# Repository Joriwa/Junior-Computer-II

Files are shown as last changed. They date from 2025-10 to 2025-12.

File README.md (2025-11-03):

# Junior Computer ][ (JC2)

Junior Computer ][ Hardware and Software

## Some History

In May 1980 the dutch Elektor magazine (org. Elektuur) published the Junior Computer, developed by Alois (Loys) Nachtmann.
The Junior was a little single board computer in the style of the MOS/Commodore KIM-1.
It featured a hex keyboard and a seven segment display, 1KB RAM and 1KB ROM with the so called Print Monitor.
The computer was driven by the MOS 6502 CPU with a clock speed of 1MHz. The peripheral IC 6532, a so-called RIOT (RAM/IO/Timer), was used for input and output.
All in all, the Junior Computer was a nice little tool that gave ambitious hobby electronics enthusiasts access to programming the 
6502 CPU and enabled them to take their first steps in the world of computer-controlled electronics. 
For many people in the 1980s, the Elektor Junior Computer was the Arduino of its time.

I never had one of those wonderful little machines back in these days, but I always wanted one...

40 years later, in January 2020, I decided to make a 40th anniversary edition of the Junior.
This time it should have more memory and a better method to insert code than with the hex keyboard, but without destroying all the glory of it's original functionality.
So I gave it a whopping 32 KB of RAM, 8 KB of ROM with an extended print monitor, and a serial interface for connecting a VT100-compatible terminal.

The Junior Computer ][ was born. 

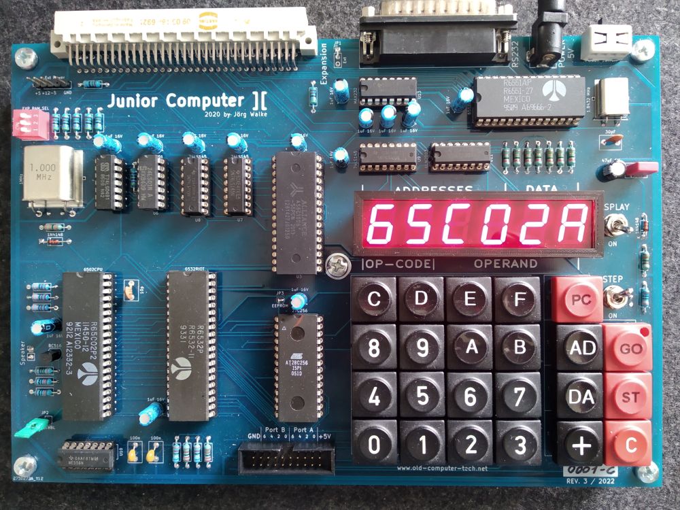
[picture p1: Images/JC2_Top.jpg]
Board Top


## The Project

For now the Junior Computer ][ has evolved various stages and some additional hardware is developed for it.

The computer it self has up to 128KB of memory. The IO-/Language card offers you a real time clock, additional parallel IO ports, 
an I2C interface, a parallel printer port, a connector for an ASCII keyboard and a Commodore Datasette drive, a 76489 sound chip, a SD-Card slot and the ability 
to program in BASIC using the EhBASIC interpreter from, the to early past away, Lee Davidson.

The Floppy-/Graphics-Controller, which is still under development, also offers you a PS/2 keyboard connection, a joystick port, a composite and RGB monitor output, and a floppy disk drive interface.

A retro style ASCII keyboard, specially developed for the Junior Computer, is also available.

There is a fork from [Emile](https://github.com/Emile666/JC2) which offers some very interesting extra features.

## Software

- M/OS 65, my little disk operating system for accessing files on SD-Card and floppy disks, is in a very early stage but already usable for loading files.

- Dietrich Lausberg ported his [CPM-65](https://github.com/Dietrich-L/CPM-65_for_JUNIOR_COMPUTER_II) to the Junior Computer][.

- Marko Lauke's port of Pacman for the [Steckschwein](https://www.steckschwein.de/) (another great new 6502 computer) is still in progress, but already looks very promising.

## Finishing

I build a wooden (bottom) case for the JC2 in a late 70's style to include all the components. The top case has to wait... 

Feel free to be inspired for building your own case.

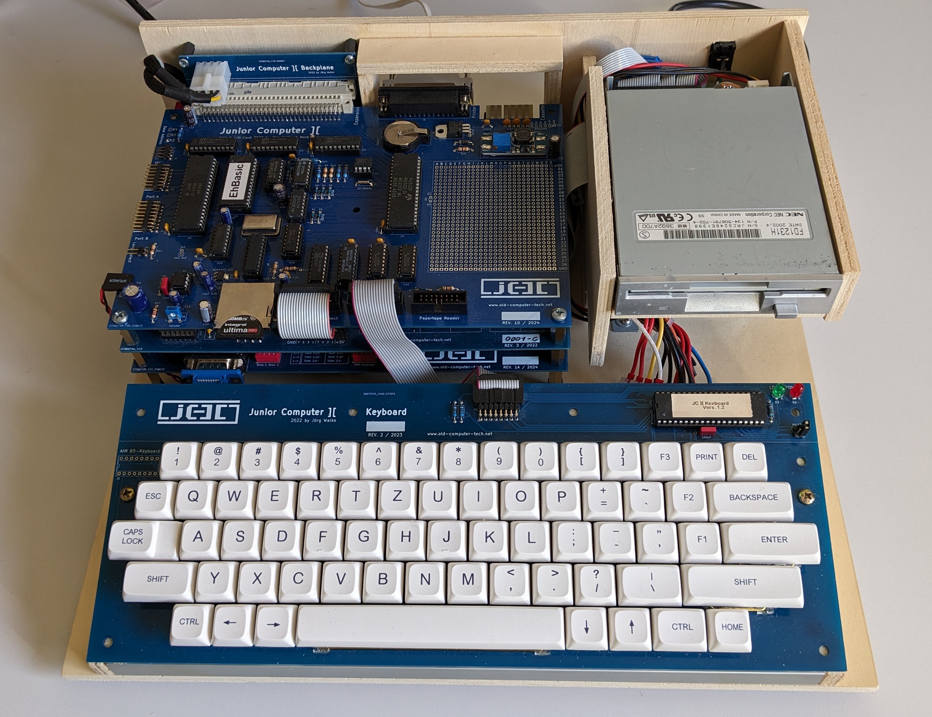
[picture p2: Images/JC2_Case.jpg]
JC2_Case


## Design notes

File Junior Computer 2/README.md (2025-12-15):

# Junior Computer 2

The Junior Computer ][ is essentially an expanded Elektor Junior Computer. It uses the same address decoding as the original, with some extra decoding to reach memory addresses beyond $1FFF.
Due to its incomplete address decoding, the Elektor Junior Computer mapped the first 8KB of the 6502's total 64KB memory space eight times in a row. 
This makes it possible to place the ROM at address range from $1C00 to $1FFF while at the same time reaching the reset and interrupt vectors at the required addresses from $FFFA to $FFFF.

The JC2 extends the address decoders of the Junior in the way to enable the use of the entire 64KB address space, without having to change any absolute addresses in the original Monitor ROM. So using old style programs should cause no problems at all.

With a 628128 RAM the JC2 can directly access 51712 bytes of free memory. The upper 64KB could be used via the 128K_SEL line on the expansion bus with some additional electronics. However, it's not currently used. 

A 6551 UART makes it possible to communitate with the JC2 via a VT100 compatible terminal or a terminal emulation such as TeraTerm, qTerm or PuTTY. The JC2 BIOS attempts to determine the baud rate used by the terminal by sending the “Send-ID” command at various baud rates until it receives a response from the connected terminal. If no response is received, JC2 uses 9600 baud, 8 bits, no parity on the COM port. You can use a little hardware patch to disable the auto baud rate detection, as described in "Hardware Patch.pdf". This patch sets the transmission rate to 19200 baud, 8 bits, no parity.

The Junior Computer ][ can be expanded with additional hardware via the 64-pin expansion bus, which is pin-compatible with the original bus interface of the Elektor Junior Computer. Therefore, old hardware expansions should also work with the JC2 but there is no guarantee that all old cards will work.

The new monitor program for the JC2 was build uppon Steve Wozniak's Apple 1 monitor program, but has since been replaced by a new implementation. However, the old postfix style of command input has been retained.

To load and save programs and data from a via RS232 connected PC to the Junior Computer's memory, I use the XModem implementation of Daryl Rictor from 2002. This uses CRC checking of the transmitted data.
In order to use CRC checking in TeraTerm, you have to modify the TeraTerm.ini file as described in the TeraTerm README.

Finally, you can make your own 3D printed cover for the 7 segment display using the JuniorLEDCover.stl file. 

## CPU

The Junior Computer ][ was originally designed for the NMOS type 6502. All code used in the BIOS is written for this CPU type. However, you can also use the Rockwell 65C02 CMOS version to reduce power consumption. The R65C02 features some additional OP-Codes. Feel free to use them for your own programs, but note that other JC2 users will not be able to run your programs without upgrading to the 65C02. 

The 6502 is still in production by Western Design Centre. They build the W65C02S CPU which is code, but not fully pin compatible to the original 6502. So you have to make some minor changes to make it fully work with the Junior Computer ][ PCB.

- The W65C02S uses pin 1 as the Vector Pull output signal, whereas the 6502 uses this as a second VSS pin, which is tied to Ground on the JC2. 
  **To solve the problem, you can remove pin 1 on your 6502 CPU IC socket or cut the trace on the component side of the PCB that connects pin 1 of the CPU socket to Ground.**

- The W65C02S also introduces a Bus Enable (BE) signal on pin 36. 
  **This signal (pin 36) must be pulled to high via a 3.3K Ohm resistor to +5V (VCC pin 8 of the CPU socket) to enable the address and data bus.**

- The RDY (Ready) signal on the W65C02S CPU is now bidirectional to monitor the WAI opcode. For this, the RDY pin is internally not pulled high any longer.
  **This signal (pin 2) must also be pulled to high via a 3.3K Ohm resistor to +5V (VCC pin 8 of the CPU socket) to enable the CPU to run.**

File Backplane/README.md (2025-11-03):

# The Backplane

The Backplane connects all your JC2 IO cards to the mainboard via the 64 pin bus connectors.
It's possible to solder a 8 pin power connector to the backplane to supply all PCBs with +5V, +12V and -5V.

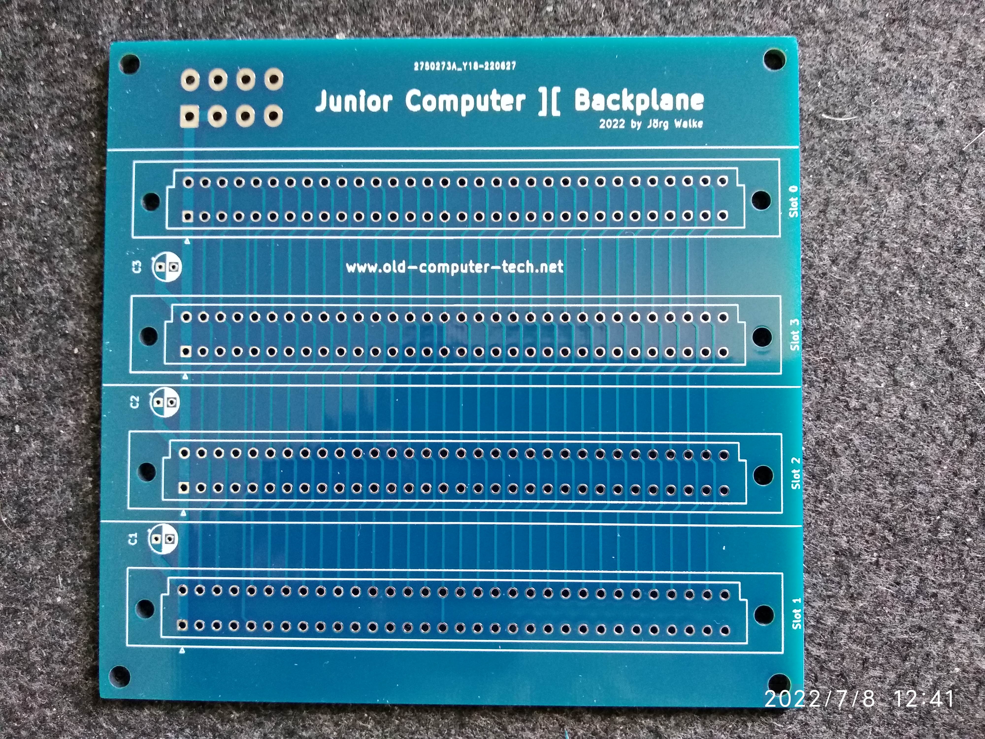
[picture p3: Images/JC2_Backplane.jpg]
JC2_Backplane


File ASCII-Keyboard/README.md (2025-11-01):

# ASCII Keyboard

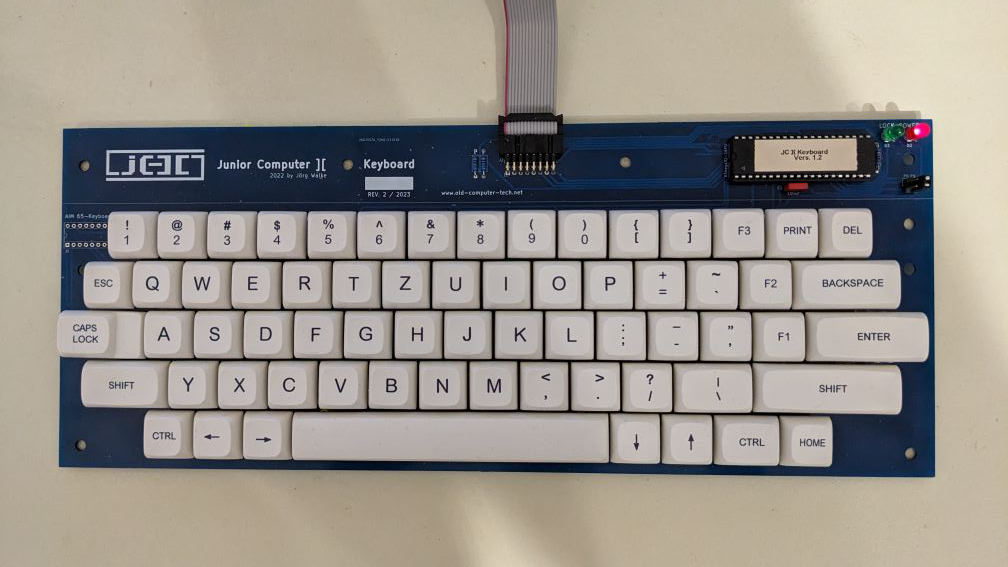
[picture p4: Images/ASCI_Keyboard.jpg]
Image top


Although the ASCII keyboard was developed specifically for the JC2, it can also be used with any other retro-style computer that can be connected to an ASCII keyboard.

Please refer to the Assembly Instruction.pdf file to find more about the pin assignment and special key combinations such as CTRL-SHIFT-DEL for a reset.

Set jumper pair P0/P1 to select desired keyboard language layout.

P0      | P1      | Keyboard Layout
--------|---------|---------------------------------------------
Open    | Open    | English US
Open    | Closed  | German
Closed  | Open    | English US (reserved for future layout)
Closed  | Closed  | English US (reserved for future layout)

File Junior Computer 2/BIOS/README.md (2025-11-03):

# Creating the BIOS

The main BIOS was assembled using the [A65](https://www.retrotechnology.com/restore/a65c.html) assembler.
In order to create a fully functional Junior Computer ][ BIOS, you must merge the assembled output of BIOS.asm with the original Monitor program. 
While BIOS.bin occupies the first 7KB of the total 8KB ROM image, MONITOR.bin uses the last 1KB. 
This last 1KB also contains the reset and interrupt vectors of the 6502 CPU. Therefore this step is absolutly necessary for a working JC2 BIOS.

However, you can use the already pre build BIOS images. "BIOS - 8K.BIN" is for a 27C64 EPROM or 28C64 EEPROM, while "BIOS - 32K.BIN" should be used for 27C256 or 28C256 ROMs.

A 32KB ROM can contain an alternative BIOS that can be selected with the ROM_BANK_SEL jumper (J4) on the JC2 mainboard. This alternative BIOS must reside from absolute ROM address $2000 to $3FFF
while the main BIOS is located between $6000 and $7FFF.

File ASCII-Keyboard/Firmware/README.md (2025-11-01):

# Firmware

To flash the ATMega32 microcontroller, you have to set the correct fuse bits as shown below.

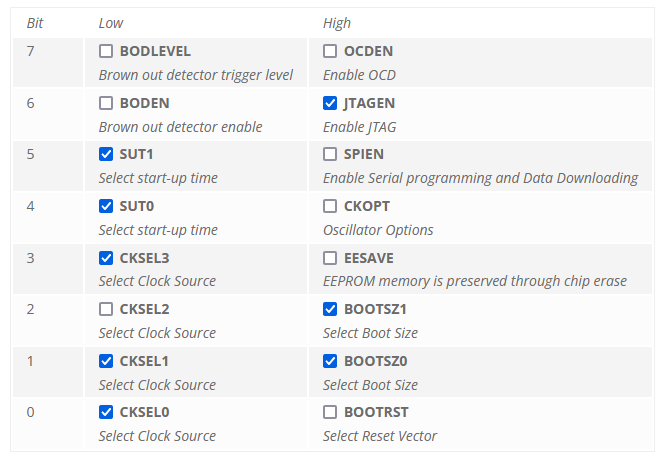
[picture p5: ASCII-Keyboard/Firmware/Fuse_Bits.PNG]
Fuse_Bits


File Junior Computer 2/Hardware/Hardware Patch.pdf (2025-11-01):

Version 1.0.2 of the BIOS includes support for a patch that can disable the automatic baud rate detection for a connected terminal and to work with the predefined speed of 19200 bauds.

For this, you must also slightly modify the Junior Computer ][ motherboard.

The simplest hardware patch is to connect pin 4 (Q3) of IC U9 (74LS145) to pin 11 (PB0) of the port connector to the left of the hex keyboard via a single wire.

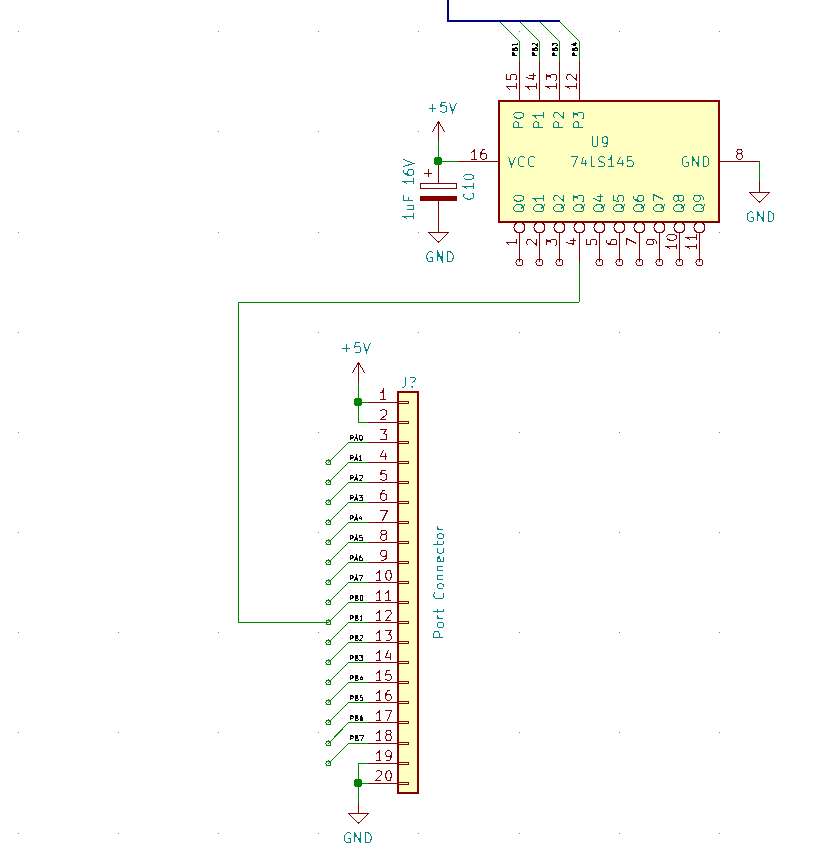
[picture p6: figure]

Figure 1. Simple patch solution

This works fine until you want to run the Junior Computer ][ without a terminal in its native Junior Computer mode using the Hex keyboard and Hex display.
Because the patch, the Junior Computer always switches into the terminal mode and the display won’t light up. To fix this issue, you can include a switch in the patch wire, to disconnect the two pins if desired.

Another solution is to exchange switch 25 (DISPLAY) into a double (toggle) switch like SW24 (STEP). If you then switch the display On (native mode), you deactivate the patch. If you insert a second switch (SW28) like in figure 2, you can additionally disable the patch completely, regardless of whether you need the Hex display or not.

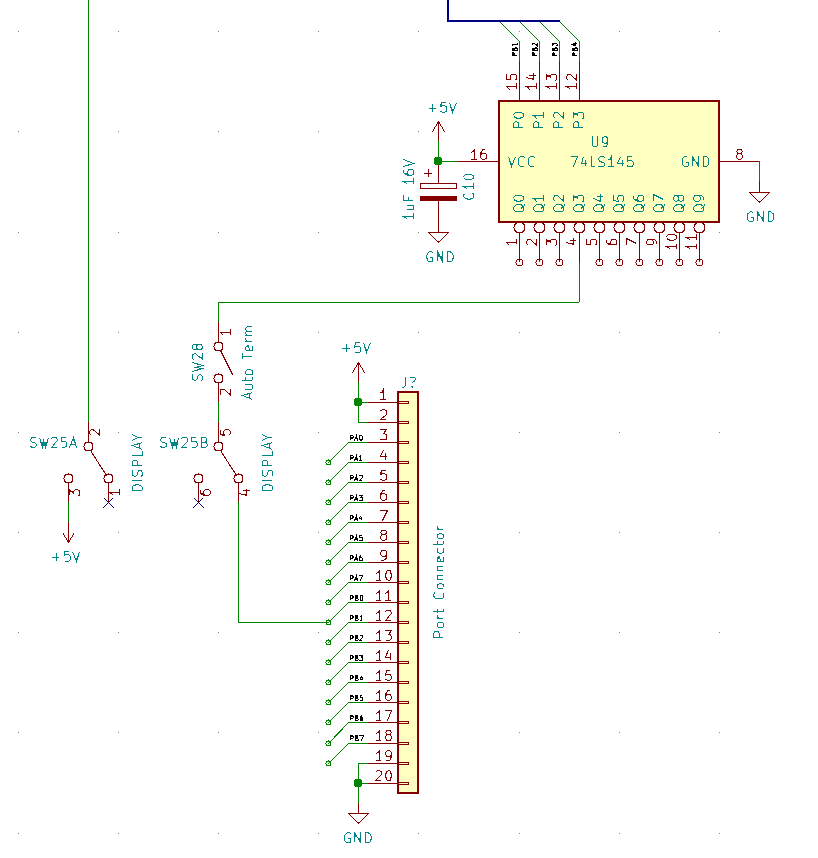
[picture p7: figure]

Figure 2. Universal patch solution

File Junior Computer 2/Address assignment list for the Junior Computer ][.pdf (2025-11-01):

## Junior Computer ][ address assignment

Address range | Size | Used by
$0000-$00FF | 256 Bytes | Zero-Page
$0100-$01FF | 256 Bytes | Stack
$0200-$07FF | 1536 Bytes | User RAM
$0800-$0BFF | 1KB | I/O area (K2)
$0C00-$0FFF | 1KB | I/O area (K3)
$1000-$13FF | 1KB | I/O area (K4)
$1400-$15FF | 512 Bytes | String- and Receive-Buffer for XMODEM communication
$1600-$17FF | 512 Bytes | 6551 ACIA serial RS232 interface
$1800-$1BFF | 1KB | 6532 RIOT, RAM, Input/Output, Timer
$1C00-$1FFF | 1KB | ROM, Junior Computer Monitor Program (mirrored address
| | range of $FC00-$FFFF)
$2000-$7FFF | 24KB | User RAM
$8000-$9FFF | 8KB | User RAM or I/O selectable via Bank80_Sel.
| | DIP-Switch $80 (ON = RAM, OFF = I/O)
$A000-$BFFF | 8KB | User RAM or I/O selectable via BankA0_Sel.
| | DIP-Switch $A0 (ON = RAM, OFF = I/O)
$C000-$DFFF | 8KB | User RAM or I/O selectable via BankC0_Sel.
| | DIP-Switch $C0 (ON = RAM, OFF = I/O)
$E000-$FFFF | 7KB | ROM, extended (serial Print) Monitor , XMODEM protocol
$FC00-$FFFF | 1KB | ROM, Junior Computer Monitor Program

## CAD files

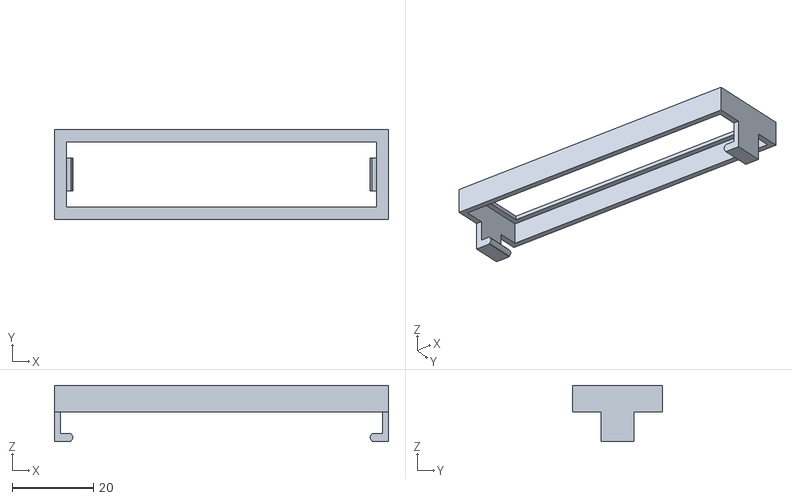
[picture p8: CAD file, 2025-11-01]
Junior Computer 2/3D Print/JuniorLEDCover.stl
82.0 x 22.0 x 13.8

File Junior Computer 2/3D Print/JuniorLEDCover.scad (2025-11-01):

$fn = 60;
/*
**  Überrahmen
*/
Xseite   =  82.0  ;   //mm
Yseite   =  22.0  ;   //mm
Zseite   =   5.5  ;   //mm
staerke  =   1.5  ;   //mm

/*
**  Filter
*/

FilterX  = 78.5 ;
FilterY  = 18.0 ;
FilterZ  = 1.0  ;

/*
**  Rahmen über LED
*/
LedX     =  78.0  ;   // led = 76 plus 2x Wand
LedY     =  18.2  ;   // led = 17,2 plus 2 x Wand
LedZ     =   5.0  ;
Wand     =   1.0  ;



module rahmen(xLength,yLength,zLength,thickness)
{
  cut = 2.0 * thickness;
  difference(){
    cube([xLength ,yLength, zLength],center = true);
    cube([xLength - cut ,yLength- cut, zLength+1],center = true);
  }
}

module Halter (){
  rahmen ( Xseite,Yseite,Zseite, staerke);
  translate ([0,0,Zseite/2.0 + 0.5]) rahmen ( Xseite,Yseite,1.0, 3.0);
}




module lippe(){
  translate ([3.5,0.0,0.0]) cylinder ( d = 2.0 , h = 8.0);
  translate ([1.0,-1.0,0.0]) cube ( [3.0,2.0,8.0]);
  translate ([0.0,-1.0,0.0]) cube ( [1.5,8.0,8.0]);
}

//lippe();

translate ([(LedX/2.0+2.0),-4.0,-9.0])  rotate([ 90.0,0.0,180.0])lippe();
translate ([-(LedX/2.0+2.0),4.0,-9.0])  rotate([ 90.0,0.0,  0.0])lippe();

Halter ();

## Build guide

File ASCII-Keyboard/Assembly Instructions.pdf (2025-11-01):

# Junior Computer ][ Keyboard rev. 2 Assembly Instructions

The assembly of the keyboard is not that easy. Therefore, please read the instructions to assemble the keyboard in the best possible way.

For assembly you need:

- A small bench vise to clamp the board vertically while you solder the key switches.
- A ruler at least 30 cm long to align the keys neatly and prevent twisting of the keys.
- Two small, strong clamps or duct tape to hold the ruler to the board.
- Of course, a soldering iron, solder, a side cutter and flat nose pliers.
- Patience and time!

Use a piece of cardboard or similar on each side of the PCB to avoid scratching the solder mask while clamping the board. Clamp the lower edge of the board horizontally in the bench vice so that it can be easily viewed from both sides.

Begin placement at the top row of the keys (1, 2, 3...).

For each row of keys, first loosely insert only the left and right keys on the PCB. Then clip the ruler with the two clamps under the two switches so that they are seated in position with as little play as possible. The keys should be aligned exactly within the silkscreen square printed on the circuit board.

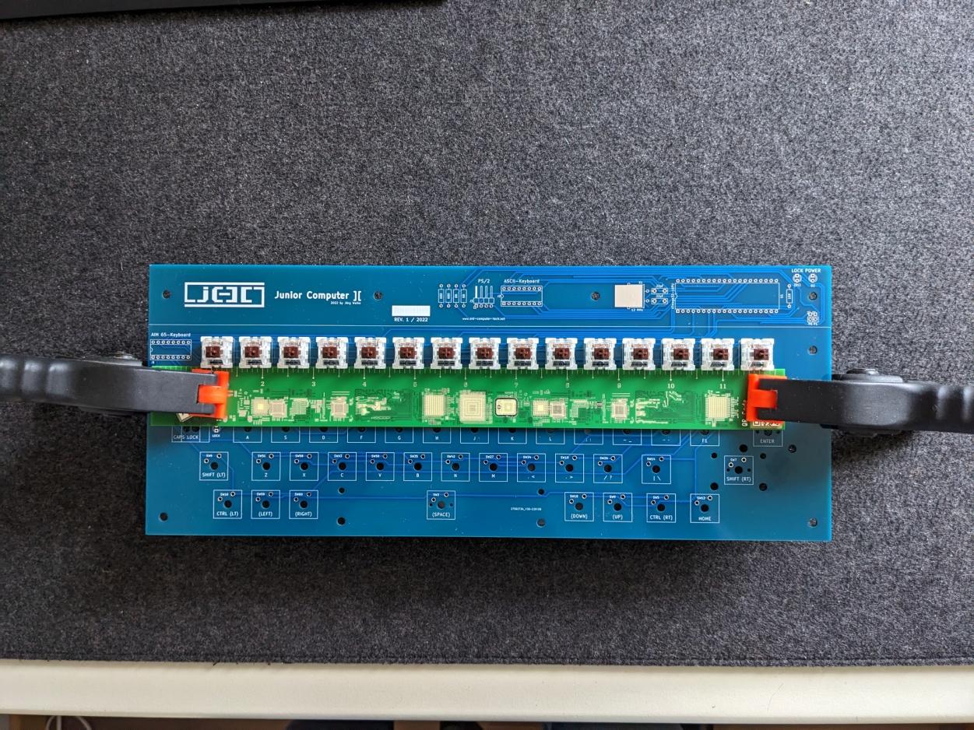
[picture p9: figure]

Press and hold the switch to be soldered with your thumb firmly on the board so that it does not shift or twist anymore and then solder one of the connection pins of the switch module. The second connection should not be soldered at this time.

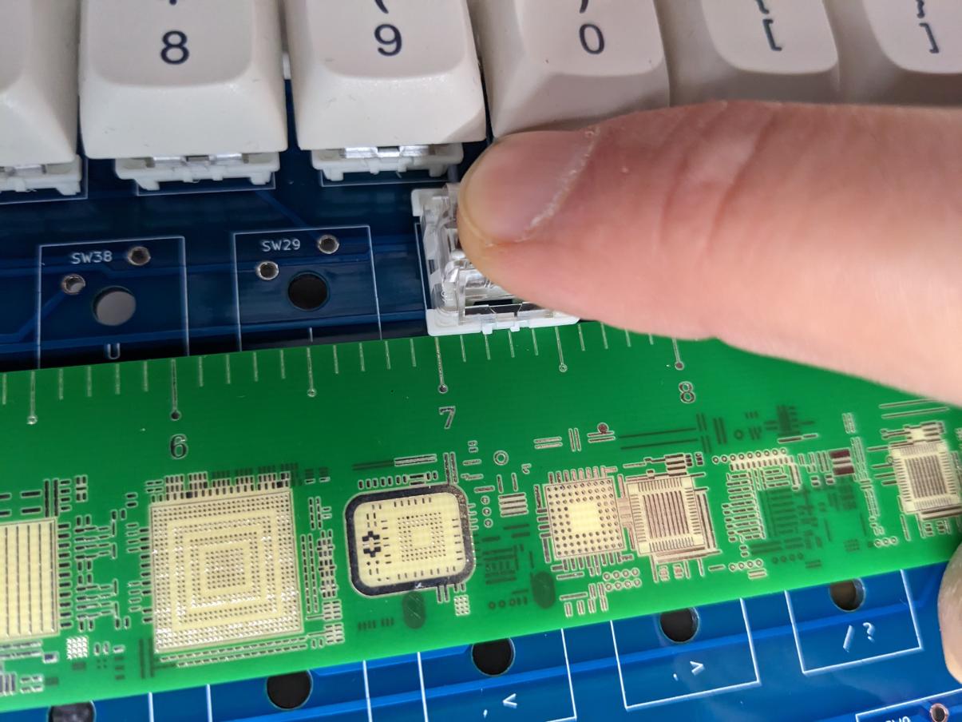
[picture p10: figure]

After that, check again, if the button is still exactly aligned to the silkscreen print and if it is not tilted in any other way. If this is not the case, re-solder the connection pin until it fits exactly.

Please take your time to get the alignment as good as possible, because every slightly twisted button will result in an unattractive appearance.

When the first two buttons of the row are properly assembled, you can now solder the second terminal pin to fix them in place.

Now equip each further switch in the row individually, as described above. The ruler helps to align the buttons at the same height. Please also leave the second connection pin unsoldered for the moment, so that you can correct any misalignment later if necessary.

When you have finished inserting a row of switches, carefully press the key caps onto the modules. This will help you to detect and correct slightly twisted or slipped buttons. Only when you are satisfied with the result, solder the remaining, second connection pins.

Equip all other rows of keys in the same way.

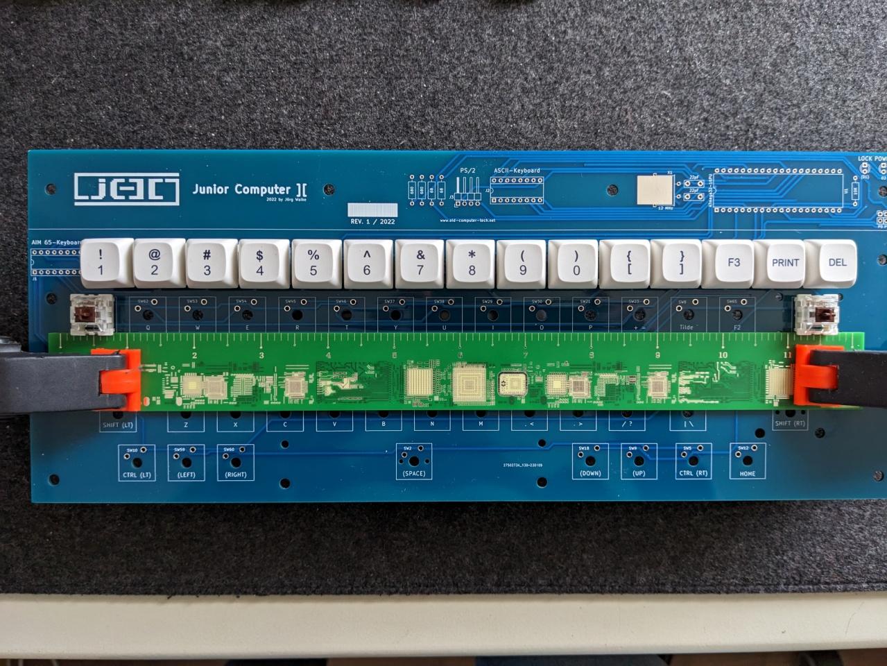
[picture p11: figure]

The key stabilizers for the wider keys are only inserted at the very end. Otherwise, they prevent the ruler from lying close to the key modules.

The keys "Backspace", "Enter", "Space" and the right "Shift" key need stabilizers. Use the key puller to remove the corresponding keycaps and possibly the keycaps of the "Home" key.

Now place the stabilizers with the two plastic noses in the two lower holes provided for the respective key. Then carefully press the two upper nubs with the metal screw connections through the holes, e.g. with a small Phillips screwdriver. Please also use some paper washers for screwing in order not to damage the solder mask with the screw heads. These are normally included with the stabilizers.

Finally assemble the three resistors, the IC socket and the LEDs according to the printed circuit board. Which LED color you take for power and which for (caps) lock is completely up to you. The Caps Lock LED D1 can be populated either on the upper right corner beside the Power LED or next to the Caps Lock key. In the second case it’s up to you to drill a hole at the right position into the Caps Lock key cap.

Pin headers P0 and P1 are used to configure the desired keyboard layout.

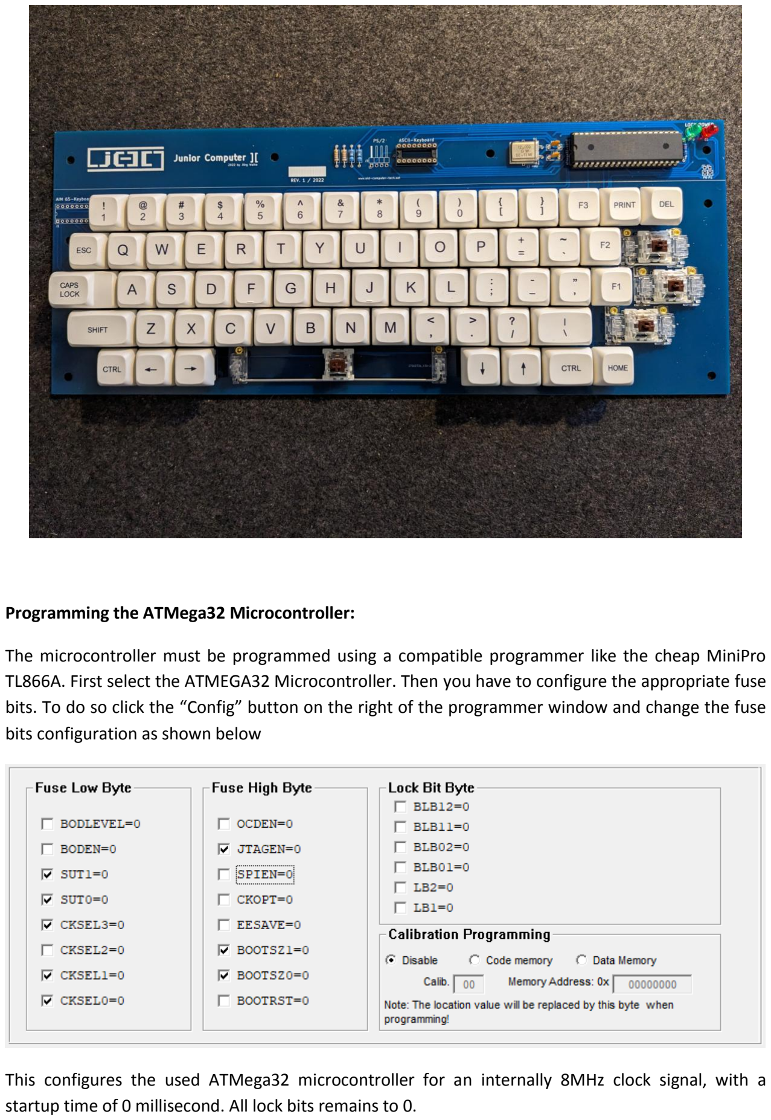
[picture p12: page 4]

Programming the ATMega32 Microcontroller:

The microcontroller must be programmed using a compatible programmer like the cheap MiniPro TL866A. First select the ATMEGA32 Microcontroller. Then you have to configure the appropriate fuse bits. To do so click the “Config” button on the right of the programmer window and change the fuse bits configuration as shown below

This configures the used ATMega32 microcontroller for an internally 8MHz clock signal, with a startup time of 0 millisecond. All lock bits remains to 0.

Then click the Code Mem0 button to switch back to the hex editor view. Load the included JC2_ASCII_Keyboard Firmware2.2.hex firmware file and click the programming button or use the menu “Device(D) -> Program(P)”. In the programming window leave all settings at the default values.

The Firmware is distributed under the Creative Commons Attribution 4.0 International License.

So you can feel free to modify the included source code file main.c to suit your needs. But if you do so, you have to give credits to me in the modified source file. To compile the source code you need the latest Microchip Studio for AVR development environment including the GNU compiler suite which can be downloaded from the Microchip website.

After you placed the microcontroller into the socket, you can apply a +5V supply voltage to the 16-pin socket (pin 2 +5V, pin 16 GND - see pin assignment). Immediately after applying the voltage the POWER LED should light up and after pressing the CAPS LOCK button once the LOCK LED should light up. A second press on CAPS LOCK switches the LED off again.

At last squeeze the two connectors onto the ribbon cable. Do this carefully to avoid accidentally breaking the connectors.

To use the keyboard on the Junior Computer ][ you need at least BIOS version 1.0.2, which can be downloaded from https://www.old-computer-tech.net/downloads and IO Board Revision 1C or newer.

Both pin 1 of the connectors on the keyboard and on the IO/Language Board is located on the left. So the cable can be plugged in 1:1.

Have fun with the keyboard

Jörg Walke, February 2024

Parts list :

Part | Count | Value | Description and Order-Link | Distributor
R1 | 1 | 10 kOhm | Metal Film Resistor 1W
R2,3 | 2 | 680 Ohm | Metal Film Resistor 1W
D1 | 1 | LED green | 5mm LED green color maybe 3mm for use in the Caps Lock
D2 | 1 | LED red | 5mm LED red color
U1 | 1 | ATMega32-16PU | ATMega32 CPU, 16 MHz
IC-Soc | 1 | IC-Socket 40 pin | 40 pin DIL precision IC-Socket
J2 | 1 | Pin Header | 2x8-pin Pin Header, angled, 2,54mm spacing
SW 1-66 | 66 | Cherry MX switch | Cherry MX switch, brown, 2 pin, 100 pcs. https://www.aliexpress.us/item/3256802260307415.html
Caps | Set | Key Caps | Milk theme key caps for MX switch mechanical keyboard. https://www.aliexpress.us/item/3256803714431360.html Set “Color” to English for US-Key Caps ! | ESC keycap Store (https://www.aliexpress.com/store/1101947944?spm=a2g0o.detail.1000007.1.153266a7Y69xRe)
Stab | Set | Key Caps Stabilizer | Mechanical Keyboard PCB Screw Stabilizers 1 x 6.25U 3 x 2U Cherry Stabilizers https://www.aliexpress.us/item/3256803460598353.html
Con1 | 1 | DIL16 crimp connector | 16 pin DIL-16 ribbon cable crimp connector for connecting to the Junior Computer ][ IO Board.
Con2 | 1 | 2x8-pin crimp connector | 2x8 pin crimp connector for ribbon cables
Cable | 1 | 16 lead ribbon cable | 30 cm, 16 lead ribbon cable

AIM 65 Connection:

The keyboard is connection compatible to an AIM 65 computer via the 16 pin DIL socket called AIM 65-Keyboard. For this the upper part of the board could also be cut off along the white separating line. If this is not done, the keyboard electronics must not be powered while an AIM 65 is connected.

If connected to an AIM 65, some additional keys will not be recognized without a change to the AIM 65 ROM, plus the keycap labels are not completely identical. The CAPS LOCK and RESET functions are generally not available on the AIM 65.

Special Keyboard Functions:

Press the SHIFT-CTRL and DEL keys simultaneously to initiate a 250 milliseconds low pulse on the /RESET line of the keyboard.

Press the HOME key to initiate a 25 milliseconds high pulse on the CLEAR_SCREEN line and generate an ASCII code (see below) on D0..D6.

Some keys on the keyboard do not have a standardized ASCII Code. The Junior Computer ][ keyboard uses the following ASCII Codes for this special keys:

Key Function | ASCII Code (decimal) and corresponding relation
LEFT ARROW | 008 Backspace (BS)
RIGHT ARROW | 021 Negative Acknowledge (NAK)
UP ARROW | 011 Vertical Tab (VT)
DOWN ARROW | 010 Line Feed (LF)
HOME | 001 Start Of Header (SOH) - CLS signal on pin 12
PRINT | 020 DC 4 (XON)
F1 | 017 DC 1
F2 | 018 DC 2 (XOFF)
F3 | 019 DC 3
CTRL-SHIFT +DEL | /RESET signal on keyboard connector pin 1
CTRL (-SHIFT) + LEFT ARROW | 006 Acknowledge (ACK). Use as Back Tab (BT)
CTRL (-SHIFT) + RIGHT ARROW | 009 Horizontal Tab (HT)
CTRL (-SHIFT) + UP ARROW | 024 Cancel. Use as Page Up (PU)
CTRL (-SHIFT) + DOWN ARROW | 012 Form Feet (FT). Use as Page Down (PD)

A key press on any key except the modifier keys (CAPS LOCK, SHIFT, and CTRL) generates a 2 microsecond low pulse on the /STROBE line. The D7 line goes low 7 microseconds before /STROBE and rises back to high 2 microseconds before /STROBE line is going low. This is used for the Junior Computer ][ as the "data available" signal.

Because data is always stable around 7 microseconds before /STROBE and stays stable until any other key is pressed, you can use the /STROBE pulse to trigger at the falling or rising edge.

The keyboard is capable of N-key roll over, which means that a freshly pressed key is detected even if another key is held down.

Pressing and holding a key for 500 milliseconds enables the auto repeat function. The standard typematic rate lies around 25 chars/s.

The keyboard generates a 7 bit ASCII code on D0..D6. The connected computer should ignore D7 for the ASCII code and set the most significant bit (MSB) of the received code to 0 (zero).

The CAPS LOCK key switches between lowercase (CAPS LOCK off) and uppercase (CAPS LOCK On) characters a..z and A..Z respectively. The number and special chars are not modified by CAPS LOCK. This is only done by pressing the SHIFT key. Pressing SHIFT while CAPS LOCK is On reverses the uppercase characters back to the lowercase ones. So CAPS LOCK behaves more like an ALPHA LOCK key.

Assignment of the 16 pin ASCII keyboard connector:

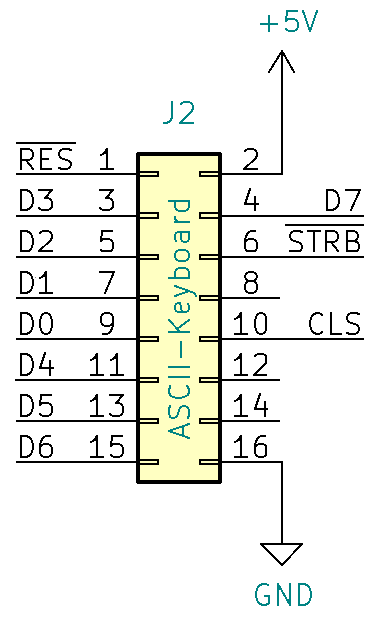
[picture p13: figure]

Top view – Pin 1 is marked as square solder pad on the PBC

Jumper P0 / P1 settings:

Set Jumper pair P0/P1 to select desired keyboard language layout.

P0 | P1 | Keyboard Layout
Open | Open | English US
Open | Closed | German
Closed | Open | English US (reserved for future layout)
Closed | Closed | English US (reserved for future layout)

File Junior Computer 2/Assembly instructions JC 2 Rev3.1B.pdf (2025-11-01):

# Junior Computer ][

2020 by Jörg Walke

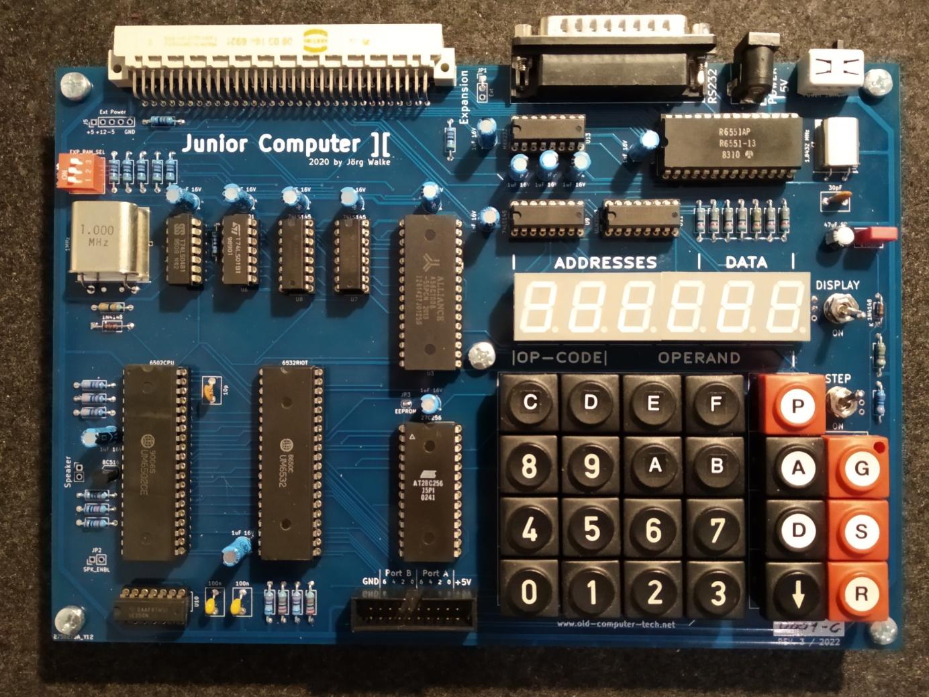
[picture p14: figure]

https://old-computer-tech.net

Preface

In May 1980 the DIY project Junior Computer was presented in the Elektor electronics magazine (originally Elektuur).

The little single-board computer was equipped with 1 KB ROM, in which the monitor program is located, 1 KB RAM (plus 128 bytes of RAM located in the 6532 RIOT), which, according to the authors, was more than enough at the time.

At the 40th anniversary of the computer, I decided to design a version with all features I wanted for the junior back in the 80s. The result is the Junior Computer ][ described here. It has 8KB ROM and a maximum of 128KB RAM. A additional serial RS232 interface and a simple sound output (as described in Junior Computer Book 2, from page 41) are also added. A 5V plug-in power supply with 2A should be sufficient. If external hardware needs to be supplied with voltage via the expansion connector, 3 Amps is recommended.

In order to be able to address the additional memory, the originally address decoding had to be extended. This is designed in such a way that the compatibility of the computer with the original Junior is preserved. An adaptation of the original monitor ROM to match the new memory location was not necessary.

Like its ancestor, the Junior Computer ][ can be expanded with external hardware via a 64-pin connection. The pin assignment oft he bus was largely retained.

In the new version, the 16 available port lines of the 6532 are available via 20-pin connector instead of a 31-pin connector.

The circuit changes mentioned here were made exclusively by me and expressly without the prior consent of the publisher Elektor, which is hopefully forgivable after 40 years. Of course, all rights to the original circuit design remain to Elektor and the authors.

Circuit diagrams, Gerber files, ROM images and other documents of the Junior Computer ][ (including this description) can be downloaded from https://old-computer-tech.net/downloads/ .

The computer and all its documents are published under the Creative Commons Attribution 4.0 license.

The original issue article, as well as the books published for the Junior Computer (volumes 1 to 4), can be downloaded from the excellent website http://retro.hansotten.nl/6502-sbc/elektuur- junior/ created by Hans Otten. Here you can also find other interesting details, programs and suggestions for the computer.

Jörg Walke , Esslingen March 20, 2022

Part | Count | Value | Description
C1 | 1 | 10pF | Ceramic capacitor
C2-C10, C14, C16-C19 | 14 | 1µF 16V | Electrolytic capacitor
C11, C12 | 2 | 100nF | Ceramic capacitor
C13 | 1 | 47µF 6V | Electrolytic capacitor
C15 | 1 | 30pF (or 27pF or 33pF) | Ceramic capacitor
D1, D2 | 2 | 1N4148 | Universal diode
Di1-Di6 | 6 | LTS-457A | 7 segment LED display 1 digit, red, common cathode, digit height 13,2 mm

or
Di1-Di6 | 2 | LTC5336WS-02 | 7 segment LED display LITEON 3 digits, red, common cathode, digit height 13,2 mm e.g. at POLLIN Electronic
R1-R3 | 3 | 3,3 K Ohm | Metal layer resistor 0,6W, 1%
R4 | 1 | 330 K Ohm | Metal layer resistor 0,6W, 1%
R5, R29 R12-R18 | 9 | 4,7 K Ohm | Metal layer resistor 0,6W, 1%
R6 | 1 | 330 Ohm | Metal layer resistor 0,6W, 1%
R7, R9 | 2 | 2,2 K Ohm | Metal layer resistor 0,6W, 1%
R8, R10 | 2 | 68 K Ohm | Metal layer resistor 0,6W, 1%
R11 | 1 | 820K | Metal layer resistor 0,6W, 1%
R19-R25 | 7 | 82 Ohm | Metal layer resistor 0,6W, 1%
R26, R27 | 2 | 10 K Ohm | Metal layer resistor 0,6W, 1%
R28 | 1 | 100 Ohm | Metal layer resistor 0,6W, 1%
U1 | 1 | R 6502 | CPU (DO NOT USE A 65C02)
U2 | 1 | 27C64, 27C128 or 27C256 or AT28C64 or AT28C256 | EPROM 8Kx8, 16Kx8 (only 8K usable) EPROM 32Kx8 (only 8K usable) EEPROM 8Kx8 (solder bridge JP3 open) EEPROM 32Kx8
U3 | 1 | W24512A or 626128 | SRAM 64Kx8 SRAM 128Kx8
U4 | 1 | UM 6532 | RIOT (RAM, Input/Output, Timer)
U5 | 1 | 74LS04 | INVERTER
U6 | 1 | 74LS01 | NAND O.C.
U7-U9 | 3 | 74LS145 | BCD Decoder O.C.
U10 | 1 | LM556 | Timer
U11 | 1 | ULN2003 | Power driver
U12 | 1 | R 6551-AP | ACIA (Asynchronious Communication Interface Adapter)
U13 | 1 | MAX232 | RS232 level shifter
X-Tal 1 | 1 | 1 MHz | Crystal, HC-33 or HC-43/U
X-Tal 2 | 1 | 1,8432 MHz | Crystal, HC-43/U
Q1 | 1 | BC516 | Darlington Transistor
LS1 | 1 | Loudspeaker 8 Ohm
J1 | 1 | DIN41612 Male 3 rows, 2x32 pin | Connector R - 64-pin, pitch 2,5 mm, THTR
J2 | 1 | D-SUB ST25-EU Male | D-SUB connector, 25-pin, angled

J3 | 1 | low voltage socket for power supply 5V DC, 2A center positiv !!! | horizontal, 6.3mm outer diameter, 2.5mm pin diameter
J4 | 1 | Pin Header 2x10 pin | Box connector 20-pol, pitch 2,5 mm
JP1 | 1 | Pin Header 1x3 | External Control Enable
JP2 | 1 | Pin Header 1x2 | Speaker Enable
JP3 | 1 | | EEPROM select
JP4 | 1 | Pin Header 1x2 with Jumper | ALT_ROM_SEL
SW26 | 1 | Slide switch POWER ON | E.g. APEM 1xOn-On or 2xOn-On pitch 2,54 mm or 5,08 mm
SW1 | 1 | Push Button Marquard 6425.0101 Keycap 826.000.071 | E.g. Conrad Labeling RST (Reset), Sticker
SW2 | 1 | Push Button Marquard 6425.0101 Keycap 826.000.071 | E.g. Conrad Labeling STP (Stop), Sticker
SW3 | 1 | Push Button Marquard 6425.0101 Keycap 826.010.011 | E.g. Conrad Labeling 0, e.g. Conrad
SW4 | 1 | Push Button Marquard 6425.0101 Keycap 826.001.011 | E.g. Conrad Labeling 1, e.g. Conrad
SW5 | 1 | Push Button Marquard 6425.0101 Keycap 826.002.011 | E.g. Conrad Labeling 2, e.g. Conrad
SW6 | 1 | Push Button Marquard 6425.0101 Keycap 826.003.011 | E.g. Conrad Labeling 3, e.g. Conrad
SW7 | 1 | Push Button Marquard 6425.0101 Keycap 826.004.011 | E.g. Conrad Labeling 4, e.g. Conrad
SW8 | 1 | Push Button Marquard 6425.0101 Keycap 826.005.011 | E.g. Conrad Labeling 5, e.g. Conrad
SW9 | 1 | Push Button Marquard 6425.0101 Keycap 826.006.011 | E.g. Conrad Labeling 6, e.g. Conrad
SW10 | 1 | Push Button Marquard 6425.0101 Keycap 826.007.011 | E.g. Conrad Labeling 7, e.g. Conrad
SW11 | 1 | Push Button Marquard 6425.0101 Keycap 826.008.011 | E.g. Conrad Labeling 8, e.g. Conrad
SW12 | 1 | Push Button Marquard 6425.0101 Keycap 826.009.011 | E.g. Conrad Labeling 9, e.g. Conrad
SW13 | 1 | Push Button Marquard 6425.0101 Keycap 826.051.011 | E.g. Conrad Labeling A, possibly Sticker
SW14 | 1 | Push Button Marquard 6425.0101 | E.g. Conrad

| | Keycap 826.052.011 | Labeling B, possibly Sticker
SW15 | 1 | Push Button Marquard 6425.0101 Keycap 826.053.011 | E.g. Conrad Labeling C, possibly Sticker
SW16 | 1 | Push Button Marquard 6425.0101 Keycap 826.054.011 | E.g. Conrad Labeling D, possibly Sticker
SW17 | 1 | Push Button Marquard 6425.0101 Keycap 826.055.011 | E.g. Conrad Labeling E, possibly Sticker
SW18 | 1 | Push Button Marquard 6425.0101 Keycap 826.056.011 | E.g. Conrad Labeling F, possibly Sticker
SW19 | 1 | Push Button Marquard 6425.0101 Keycap 826.000.011 | E.g. Conrad Labeling AD (Address), Sticker
SW20 | 1 | Push Button Marquard 6425.0101 Keycap 826.000.011 | E.g. Conrad Labeling DA (Data), Sticker
SW21 | 1 | Push Button Marquard 6425.0101 Keycap 826.017.011 | E.g. Conrad Labeling +, possibly Sticker
SW22 | 1 | Push Button Marquard 6425.0101 LED Optional Keycap 829.000.071-00 (with LED drilling) | e.g. Conrad Labeling GO, Sticker
SW23 | 1 | Push Button Marquard 6425.0101 Keycap 826.000.071 | e.g. Conrad Labeling PC, Sticker
SW24 | 1 | Toggle switch 2 x ON-ON, 5mm screw | Labeling STEP
SW25 | 1 | Toggle switch 1 x ON-ON, 5mm screw | Labeling DISPLAY
SW27 | 1 | DIP-Switch | 3xON
OPT1 | 2 | Socket strip, 1x30, 2,54 mm | Socket for LED-Display
DIL1 | 3 | DIL 14-pin | IC-Socket
DIL2 | 5 | DIL 16-pin | IC-Socket
DIL-3 | 3 (2) | DIL 28-pin | IC-Socket
DIL-4 | 1 | DIL 32-pin | IC-Socket instead of 1xDIL 28
DIL-5 | 2 | DIL 40-pin | IC-Socket

Alt
SW1-
SW23
23 | Omron B3S-1002P | Alternative input switches

### Assembly Instructions

Display

In order to raise the 7-segment LED displays to the level of the keyboard and, of course, to make it easier to replace the modules, I recommend installing two 30-pin socket. To make soldering easier, the display modules should first be plugged into the sockets before they soldered in. The solder pads 31 on the far right of the sockets are for +5V Display supply voltage. You can use it for own made plug-in PCBs such as Dot-Matrix LED Displays.

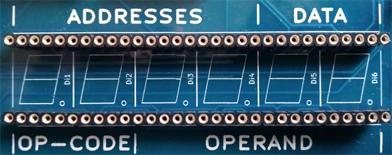
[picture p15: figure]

Instead of the six 1-digit 7-segment displays, three 2-digit or two 3-digit displays with the same digit height and a common cathode can also be installed. However, the pin assignments should be compared with the specified modules.

Keyboard

The standard Marquard button modules without a LED have a bulge in one corner and two pin bushings for an optional LED. These are suitable for the SW22's existing LED connections on the circuit board.

The cathode of the status LED for the STEP mode (button SW22, labeled GO), must be soldered to the square solder pad.

As an alternative keyboard assembly, SMD buttons with 4.5mm contact spacing can be soldered onto the existing pads.

Other Stuff

- Jumper bridge JP1 is used to enable/disable the onboard address decoder. Pin 1 is marked with a square solder pad. In the EXT position (JP1 pin 2-3), the two 74LS145 address decoders can be enabled/disabled via the pin C-30 (EXT) of the expansion slot J1. If C-30 is high , the select signals K2-K7 (K7 is equal to ROM_SEL) , RAM_SEL and the BANKx0_SEL kept high by pull-up resistors. These signals can then be activated by external hardware via the expansion slot J1 on the respective pin.
If no external control is required, JP1 must be bridged via pin 1 and 2, otherwise the computer will not start!
As an alternative, a 4.7 KOhm resistor can be soldered between pin 1 and pin 2 of JP1. Also bridge pin 2 and pin 3 of JP1. This pulls an open EXT connection at J1 to low.
- The loudspeaker amplifier can be activated with JP2. The speaker output can then be addressed as described in the Elektor Junior Computer Book 2, page 41.
- The three DIP switches (EX_RAM_SEL) can be used to page in 8KB of RAM to the specified memory area ($80 = $8000-$9FFF, $A0 = $A000-BFFF, $C0 = $C000-$EFFF).
- When using memory larger than 64KB, bank switching can be implemented via the expansion bus pin C-6 (/128K_SEL).
- The lower two kilobytes of RAM of the Junior Computer ][ are selected via the interconnected pins 1 and 2 of the BCD decoder U8 (74LS145). By connecting the (U8) IC pins 3 to 5 (or the corresponding K2 to K4 lines on the bus) with the IC pins 1 and 2 (/RAM_SEL on the bus), a maximum of three additional kilobytes of RAM can be added to the lower memory address location, if required. However, these 1-kilobyte address areas are then no longer available for any I/O expansions.
- JP3 (EEPROM) must be left open if you want to use a 64KB EEPROM, else it must be closed with a solder blob. Please note the overview table for the assignment of the Junior Computer ][ ROM socket.
- On Pin header J5 (Ext Power) the Junior Computer ][ can be connected with the supply voltages of +5V, +12V and -5V via an external power pack. Additional +12V and -5V are then available on the expansion bus for old expansion cards.
- If you want to supply your Junior Computer with a single +5V power supply via the power jack, it’s possible to generate the +12V and -5V voltages via DC-DC converters out of the +5V on J5 . The two generated voltages can then fed back to the respective pins on J5.
- The power supply connection on J3 does not have any polarity protection by a diode. Since the output voltage of a modern 5V switching power supply is almost exactly 5V, the voltage drop across a protective diode would usually be too high to safely operate the circuit.
It is therefore very important to ensure that the connector oft he power-pack is center positive, i.e. the inner pole is +5V. The following symbol should be found on the power supply unit.

If the power supply is connected incorrectly, the components of the Junior Computer ][ can be destroyed.

- The two toggle switches SW24 (STEP) and SW25 (DISPLAY) must be connected from the downside of the board as follows.

On the left the switch for DISPLAY On/Off, right STEP On/Off

- The on/off switch SW26 can be used with one or two poles either with a pitch of 2.54mm or 5.08mm.
- All component values are printed on the circuit board. A resistance value of 3k3 means 3.3KOhm, 82 means 82 Ohm.
- The plus pole of electrolytic capacitors is marked with a small + sign.
- The cathode of the diodes D1 and D2 are marked with a thicker bar in the component symbol on the circuit board.
- If the 7-segment displays are too bright or too dark, the 82 ohm series resistors R19-R25 can be varied from 68 ohms (brighter) to 120 ohms (darker).

You can use 8, 16 or 32KB (E)EPROMs on the board. However, the Junior Computer's 1-kilobyte monitor program must be located in the upper 1024 bytes of the ROM. With an 8KB EPROM it should located on address 1C00H to 1FFFH, with 16KB from 3C00H to 3FFFH and with 32KB from 7C00H to 7FFFH. The ROM images available on my side already contain the original Junior Monitor including my Extended Monitor starting from address F800H.

The revision 3.1B board contains an additional jumper (JP4) ALT_ROM_SEL, with which address line A14 can be toggled on 32KB ROMs. This means that you can use two different ROM versions.

Board revision 3b and newer, only supports 32-pin SRAMs (64KB or 128KB) with an additional CS2. This is connected to the processor clock Phi2 in order to guarantee correct memory timing with 6502 processors in CMOS design.

For older Revision 3 boards, the RAM patch must be carried out. Revision 2 boards can only be used with 1MHz 6502 NMOS processors, otherwise unexpected memory problems may occur.

### Assignment of the Junior Computer ][ ROM socket

27C256 | 27C128 | 27C64 | 28C256 | 28C64 | | Dual-In-Line-Package | | 28C64 | 28C256 | 27C64 | 27C128 | 27C256
VPP | VPP | VPP | A14 | RDY | 1 | | 28 | VCC | VCC | VCC | VCC | VCC
A12 | A12 | A12 | A12 | A12 | 2 | | 27 | WE_ | WE_ | PGM_ | PGM_ | A14
A7 | A7 | A7 | A7 | A7 | 3 | | 26 | NC | A13 | NC | A13 | A13
A6 | A6 | A6 | A6 | A6 | 4 | | 25 | A8 | A8 | A8 | A8 | A8
A5 | A5 | A5 | A5 | A5 | 5 | | 24 | A9 | A9 | A9 | A9 | A9
A4 | A4 | A4 | A4 | A4 | 6 | | 23 | A11 | A11 | A11 | A11 | A11
A3 | A3 | A3 | A3 | A3 | 7 | | 22 | OE_ | OE_ | OE_ | OE_ | OE_
A2 | A2 | A2 | A2 | A2 | 8 | | 21 | A10 | A10 | A10 | A10 | A10
A1 | A1 | A1 | A1 | A1 | 9 | | 20 | CE_ | CE_ | CE_ | CE_ | CE_/PGM
A0 | A0 | A0 | A0 | A0 | 10 | | 19 | I/O7 | I/O7 | O7 | O7 | O7
O0 | O0 | O0 | I/O0 | I/O0 | 11 | | 18 | I/O6 | I/O6 | O6 | O6 | O6
O1 | O1 | O1 | I/O1 | I/O1 | 12 | | 17 | I/O5 | I/O5 | O5 | O5 | O5
O2 | O2 | O2 | I/O2 | I/O2 | 13 | | 16 | I/O4 | I/O4 | O4 | O4 | O4
GND | GND | GND | GND | GND | 14 | | 15 | I/O3 | I/O3 | O3 | O3 | O3

### Using the solder bridge JP3 (EEPROM)

Leave solder bridge JP3 open for 28C64 assembly

Close solder bridge JP3 for 27C64/27C128/27C256/28C256 assembly

Document Version 0.1. Courtesy of Meinolf Schmid.

### Junior Computer ][ Print Monitor ROM 0.9 Usage

If no terminal is connected or detected, the behavior of the Junior Computer ][ is exactly like the original Junior Computer.

Connect a VT100 compatible terminal configured with 2400, 3600, 4800, 7200, 9600 or 19200 baud, 8 bits, no parity, 1 stop bit.

If the keyboard does not respond, select a higher baud rate (e.g. 2400 baud does not work with the ESP32 terminal).

Turn the Junior Computer ][ on.

With the latest ROM version and Rev. 3 boards with auto reset, the main screen appears immediately.

Without Auto Reset, press RST (Reset) button once.

For older ROM versions, or simply if you want to start the Print Monitor manually:

Press the AD (address) button and enter the address F800 on the hex keyboard, then confirm with the GO button.

Input is not case sensitive, so typing 'M' or 'm' is the same.

Maximum input line length is 255 characters.

In Hex Monitor:

On the promt *

- type (hex) address to show single data byte

*E000

E000- 4C

- type start-address and end-address, divided by . (dot) to show data block

*E000.E008

E000- 4C 05 E2 4C AD E3 4C 5D E0

- type address followed by : (colon) and then followed by (hex) data to enter one or more data bytes into memory

*200: 4C 00 F8

0200- 03

- type address followed by G to run user program

*200G

0200- 4C

- type Q (quit) to return to main Monitor.
- By entering M(onitor), the original Junior Computer Monitor program can be called.

More commands are described in the PrintMonitor documentation.

Since the print monitor is still under development, there are no fixed entry point addresses for helper routines. If available, I will post a list of such entry points.

### Bus Pin Assignment

a1 +5V | c1 +5V
a2 N.C. | c2 N.C.
a3 N.C. | c3 N.C.
a4 GND | c4 GND
a5 /RES | c5 RDY
a6 /128K_SEL | c6 /BANKC0_SEL
a7 D1 | c7 D0
a8 D3 | c8 D2
a9 D5 | c9 D4
a10 D7 | c10 D6
a11 /BANKA0_SEL | c11 /BANK80_SEL
a12 /IRQ | c12 /NMI
a13 N.C. | c13 N.C.
a14 K7 | c14 S0
a15 K5 | c15 K6
a16 ------------------------ c16 (a16 connected with c16)
a17 K4 | c17 +12V
a18 -5V | c18 K3
a19 A15 | c19 A14
a20 A13 | c20 A12
a21 A11 | c21 A10
a22 A9 | c22 A8
a23 A7 | c23 A6
a24 A5 | c24 A4
a25 A3 | c25 A2
a26 A1 | c26 A0
a27 PHI2 | c27 N.C.
a28 N.C. | c28 K2
a29 /RAM_SEL | c29 R/W
a30 PHI1 | c30 EXT
a31 RAM-R/W | c31 N.C.
a32 GND | c32 GND

### RS232 – SUB-D25 socket assignment

Default RS232 | Additional RS232 channel with extra assignments
Pin 2 | TxD | Pin 9 | +5V – supply voltage for ESP32 Terminal
Pin 3 | RxD | Pin 10 +5V - supply voltage for ESP32 Terminal
Pin 4 | RTS | Pin 11 +5V - supply voltage for ESP32 Terminal
Pin 5 | CTS | Pin 14 TxD - TTL Level
Pin 7 | GND | Pin 16 RxD - TTL Level
Pin 25 GND – Ground for ESP32 Terminal and CTS Pulldown

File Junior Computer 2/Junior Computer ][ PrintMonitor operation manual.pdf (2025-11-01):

## Junior Computer ][ PrintMonitor operation manual

If no terminal is connected or recognized, the Junior Computer ][ behaves exactly like the original Junior Computer.

If a VT100 compatible terminal is connected, it must be configured as follows:

2400, 3600, 4800, 7200, 9600 oder 19200 Baud
8 Bit, No Parity, 1 Stop Bit

The actual terminal baud rate is automatically recognized by the Junior Computer ][.

If the keyboard does not respond, a higher baud rate may need to be selected. For example, a transmission rate of 2400 baud will not work with the ESP32 terminal.

With the latest ROM version and a revision 3 board, an automatic power-on reset occurs and the speaker beeps once. For older versions of the board or if there is no beep, the RST (Reset) button must be pressed once.

The advanced monitor can be called manually by pressing the AD (address) key, entering the address E000 using the hex keyboard, and then pressing the GO key.

If no connected terminal is recognized, the computer jumps back to the reset address 1C1Dh of the original Junior Computer ROM. Otherwise the start screen is displayed and the hex monitor can be started by pressing the M key. If no Language Card is found, the BIOS jumps directly into the monitor and prompts you for input.

When using a terminal, you should always set the DISPLAY switch on the Junior Computer's motherboard to the OFF position to reduce power consumption. Also, the resistors just above the display will get very hot if you leave the switch in the ON position.

All inputs are not case sensitive. So 'M' and 'm' are interpreted as equal.

The maximum input length in the hex monitor is 255 characters.

The input prompt is displayed in the hex monitor

*

Here you can enter the following commands:

- Enter a hexadecimal address and confirm with <RETURN> to display the content of a single memory address.

*E000

E000- 4C

- Enter a start and end address separated by a . (period) to show a block of memory.

*E000.E008

E000- 4C DC F8 A4 F8 B1 F6 E6 F8

The listing can be interrupted at any time by pressing the <ESC> key.

- A dump command followed by a PD (print dump) command outputs the data to a connected parallel port printer.
- To change the data of a specified address, enter the address followed by : (colon).
Then enter one or more (hex) data bytes and finally confirm with <RETURN>.

*200: 4C 00 F8

- [startaddress] G (Go) jumps to a user routine and executes it

*200G

0200-R

If no start address is specified, the command jumps to the last address stored in the address register. If the called program terminates with an RTS op-code (ReTurn from Subroutine), the GO command automatically returns to the print monitor.

- Inputs can be cascaded

* E000 200.202

E000- 4C
0200- 4C 00 F8

[startaddress[.endaddress]] L (List) disassembles the 6502 instructions starting from the last specified address. If no end address is specified, the next 23 instructions are displayed.

*E000L

E000- 4C 00 F8 | JSR | $F800
E003- AD 01 16 | LDA | $1601
E006- 29 08 | AND | #$08
E008- F0 F9 | BEQ | $F808
E030- 8D 00 16 | STA | $1600

*L

E033- 60 | RTS
E034- A2 02 | LDX | #$02
- [startaddress[.endaddress]] P - like L, but outputs the data to a connected parallel port printer.

- LM (Load from Modem) starts the XMODEM/CRC read mode.

The message "Begin data transfer. Press <ESC> to abort" is shown on the terminal.

The loading process can be aborted by pressing the <ESC> key. In the terminal, select the file that you want to send to the junior computer. If the download is completed without errors, the message "Transfer successful" is displayed. Otherwise the message "Transfer error" appears and the loading process has to be repeated.

The full command is:

[startaddress [ . endaddress]] LM

where all values in square brackets are optional. If the LM command is entered without any additional parameters, the load routine reads the start address under which the data is to be stored from the first two bytes of the data stream.
If a start address is specified, the first two bytes of the data stream are ignored and the data is stored at the specified address.

The XMODEM protocol always loads and stores complete data blocks with a size of 128 bytes. If the file to be loaded has a size that is not a multiple of 128 bytes, the remaining data bytes are padded with the value 1Ah and written to memory.

By specifying an end address, overwriting of data in memory can be prevented.

Examples:

LM | reads data from an input file to the address specified in the first two bytes
2000 LM | reads data from an input file and stores it at address 2000h
300.400 LM | reads data from an input file and stores it at address 300h up to and including address 400h

After loading, the monitor returns to the prompt. There, by entering G (Go), a possibly loaded program can be executed immediately without specifying a start address.

- SM (Save to Modem) starts the XMODEM/CRC write Mode.

The message "Begin data transfer. Press <ESC> to abort” is displayed. Pressing the <ESC> key aborts the saving process. The name of the file to be received must now be selected in the terminal program. If the save process is completed without errors, the message "Transfer successful" is displayed. Otherwise the message "Transmission error" appears and the saving process has to be repeated.

The full command is:

startaddress . endaddress SM

A memory dump from the start address up to and including the end address is written to the output file.

The first two data bytes of the output file contains the start address in LSB MSB format. So with a start address of 2400h, the first two bytes are 00 24.

It is written in complete data blocks of 128 bytes each. Missing bytes are filled with the value 00h.

Example:

2000.21FF SM writes all data from address 2000h up to and including 21FFh to an output file

Your terminal or terminal emulation must support the XMODEM protocol with 16-bit CRC check. The simple checksum error detection is not supported.

- Q (Quit). Returns to the start screen.
- M (Monitor). Calls the original Junior Computer Monitor program at address 1C1Dh.

Be sure to set the DISPLAY switch on the Junior Computer‘s Mainboard to the ON position if you jump from terminal mode to the original monitor.

### Extended Commands

If you have connected the IO/Language Card to your Junior Computer ][, you can use the following monitor commands to save and load data from a connected Commodore 1530/1531 or compatible Datasette drive. The IO board uses the standard board edge connector that is used on PET, VIC20 or C64 computers. However, the storage format of the Junior ][ is not compatible to that of these computers. It is much faster and more compact, but also reliable.

- LT (Load from Tape). This command loads previously saved data from tape.

„Press PLAY, <ESC> to cancel.“ is displayed on the terminal. If you press the <ESC> key, the command is canceled. After you press the PLAY key on your attached Datasette drive, the next file on tape is read back into the memory. The start address on where the data is stored is read from the tape file header.

The full command is:

LT [“filename“]

where filename is optional. If the LT command is entered without a filename, the next file that is found on tape will be read into memory. This is the same as giving an empty (““) or a star (“*“) string as a filename.

However, if a filename is given, all files with different file names are skipped until the matching on is found. You can append a star character to your given filename. This allows you to search for the next file whose filename starts with the given string, but does not have to match with the then following characters.

You can always break the loading by pressing the STOP key on the Datasette drive.

If a file could not correctly read back from tape, a LOAD ERROR is shown.

- ST (Save to Tape). Store data onto a tape drive. The data file is written to tape with a simple XOR checksum to detect bit errors.

The full command is:

startaddress . endaddress ST “filename“

A filename must be given for the storage file. However it can be an empty string (““) or a star (“*“). In this case the data is saved as an unnamed file.

On the Terminal the message „Press PLAY & RECORD, <ESC> to cancel.“ is displayed. You can press the <ESC> key to cancel the command. After pressing the PLAY and RECORD button at the same time, the data from memory will be written to tape from the specified start address to the given end address.

You can always break the data storage by pressing the STOP key on the Datasette drive.

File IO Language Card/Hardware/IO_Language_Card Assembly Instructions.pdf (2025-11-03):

# Parts List for the Junior Computer ][ IO/Language Card Rev. 1D

Reference | Quantity | Value | Description and Order-Link | Distributor
C1-C8, C14,C24,C26 | 11 | 100nF | KERKO 100N (https://www.reichelt.de/keramik-kondensator-100-nf-20-80-y5v-50-100-v-rm-5-kerko-100n-p9265.html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) Ceramic (https://www.reichelt.de/keramik-kondensator-100-nf-20-80-y5v-50-100-v-rm-5-kerko-100n-p9265.html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) C (https://www.reichelt.de/keramik-kondensator-100-nf-20-80-y5v-50-100-v-rm-5-kerko-100n-p9265.html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)apacitor (https://www.reichelt.de/keramik-kondensator-100-nf-20-80-y5v-50-100-v-rm-5-kerko-100n-p9265.html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), 5m (https://www.reichelt.de/keramik-kondensator-100-nf-20-80-y5v-50-100-v-rm-5-kerko-100n-p9265.html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)m (https://www.reichelt.de/keramik-kondensator-100-nf-20-80-y5v-50-100-v-rm-5-kerko-100n-p9265.html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) spacing (https://www.reichelt.de/keramik-kondensator-100-nf-20-80-y5v-50-100-v-rm-5-kerko-100n-p9265.html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) | Reichelt.de
C9,C12,C13 | 3 | 10uF 16V | RAD 10/35 (https://www.reichelt.de/elko-radial-10-f-35-v-rm-2-0-85-c-2000h-20--rad-10-35-p23716.html?trstct=pol_0&nbc=1) Electrolytic (https://www.reichelt.de/elko-radial-10-f-35-v-rm-2-0-85-c-2000h-20--rad-10-35-p23716.html?trstct=pol_0&nbc=1) C (https://www.reichelt.de/elko-radial-10-f-35-v-rm-2-0-85-c-2000h-20--rad-10-35-p23716.html?trstct=pol_0&nbc=1)apacitor (https://www.reichelt.de/elko-radial-10-f-35-v-rm-2-0-85-c-2000h-20--rad-10-35-p23716.html?trstct=pol_0&nbc=1), radial, (https://www.reichelt.de/elko-radial-10-f-35-v-rm-2-0-85-c-2000h-20--rad-10-35-p23716.html?trstct=pol_0&nbc=1) 2. (https://www.reichelt.de/elko-radial-10-f-35-v-rm-2-0-85-c-2000h-20--rad-10-35-p23716.html?trstct=pol_0&nbc=1)5m (https://www.reichelt.de/elko-radial-10-f-35-v-rm-2-0-85-c-2000h-20--rad-10-35-p23716.html?trstct=pol_0&nbc=1)m (https://www.reichelt.de/elko-radial-10-f-35-v-rm-2-0-85-c-2000h-20--rad-10-35-p23716.html?trstct=pol_0&nbc=1) spacing (https://www.reichelt.de/elko-radial-10-f-35-v-rm-2-0-85-c-2000h-20--rad-10-35-p23716.html?trstct=pol_0&nbc=1) | Reichelt.de
C10 | 1 | 220uF 35V | RAD 220/35 (https://www.reichelt.de/elko-radial-220-f-35-v-rm-5-0-85-c-2000h-20--rad-220-35-p15120.html?search=RAD+220/35) Electrolytic (https://www.reichelt.de/elko-radial-220-f-35-v-rm-5-0-85-c-2000h-20--rad-220-35-p15120.html?search=RAD+220/35) C (https://www.reichelt.de/elko-radial-220-f-35-v-rm-5-0-85-c-2000h-20--rad-220-35-p15120.html?search=RAD+220/35)apacitor (https://www.reichelt.de/elko-radial-220-f-35-v-rm-5-0-85-c-2000h-20--rad-220-35-p15120.html?search=RAD+220/35), radial, (https://www.reichelt.de/elko-radial-220-f-35-v-rm-5-0-85-c-2000h-20--rad-220-35-p15120.html?search=RAD+220/35) 5m (https://www.reichelt.de/elko-radial-220-f-35-v-rm-5-0-85-c-2000h-20--rad-220-35-p15120.html?search=RAD+220/35)m (https://www.reichelt.de/elko-radial-220-f-35-v-rm-5-0-85-c-2000h-20--rad-220-35-p15120.html?search=RAD+220/35) spacing (https://www.reichelt.de/elko-radial-220-f-35-v-rm-5-0-85-c-2000h-20--rad-220-35-p15120.html?search=RAD+220/35) | Reichelt.de
C11 | 1 | 47nF 63V | MMK 47n 63 (https://www.reichelt.de/folienkondensator-47nf-63v-100-c-mmk-47n-63-p206603.html?search=MMK+47n) Film (https://www.reichelt.de/folienkondensator-47nf-63v-100-c-mmk-47n-63-p206603.html?search=MMK+47n) C (https://www.reichelt.de/folienkondensator-47nf-63v-100-c-mmk-47n-63-p206603.html?search=MMK+47n)apacitor (https://www.reichelt.de/folienkondensator-47nf-63v-100-c-mmk-47n-63-p206603.html?search=MMK+47n), (https://www.reichelt.de/folienkondensator-47nf-63v-100-c-mmk-47n-63-p206603.html?search=MMK+47n) 5m (https://www.reichelt.de/folienkondensator-47nf-63v-100-c-mmk-47n-63-p206603.html?search=MMK+47n)m spacing (https://www.reichelt.de/folienkondensator-47nf-63v-100-c-mmk-47n-63-p206603.html?search=MMK+47n) | Reichelt.de
C15-C17 | 3 | 470pF | KERKO 470P (https://www.reichelt.de/keramik-kondensator-470p-kerko-470p-p9295.html?&trstct=pos_0&nbc=1) Ceramic (https://www.reichelt.de/keramik-kondensator-470p-kerko-470p-p9295.html?&trstct=pos_0&nbc=1) C (https://www.reichelt.de/keramik-kondensator-470p-kerko-470p-p9295.html?&trstct=pos_0&nbc=1)apacitor 2. (https://www.reichelt.de/keramik-kondensator-470p-kerko-470p-p9295.html?&trstct=pos_0&nbc=1)5mm (https://www.reichelt.de/keramik-kondensator-470p-kerko-470p-p9295.html?&trstct=pos_0&nbc=1) spacing (https://www.reichelt.de/keramik-kondensator-470p-kerko-470p-p9295.html?&trstct=pos_0&nbc=1) | Reichelt.de
C18-C21 | 4 | 1uF 16V | RAD 1/63 (https://www.reichelt.de/elko-radial-1-0-f-63-v-rm-2-0-85-c-2000h-20--rad-1-63-p15096.html?trstct=pol_1&nbc=1) Electrolytic (https://www.reichelt.de/elko-radial-1-0-f-63-v-rm-2-0-85-c-2000h-20--rad-1-63-p15096.html?trstct=pol_1&nbc=1) C (https://www.reichelt.de/elko-radial-1-0-f-63-v-rm-2-0-85-c-2000h-20--rad-1-63-p15096.html?trstct=pol_1&nbc=1)apacitor (https://www.reichelt.de/elko-radial-1-0-f-63-v-rm-2-0-85-c-2000h-20--rad-1-63-p15096.html?trstct=pol_1&nbc=1), radial, (https://www.reichelt.de/elko-radial-1-0-f-63-v-rm-2-0-85-c-2000h-20--rad-1-63-p15096.html?trstct=pol_1&nbc=1) 2. (https://www.reichelt.de/elko-radial-1-0-f-63-v-rm-2-0-85-c-2000h-20--rad-1-63-p15096.html?trstct=pol_1&nbc=1)5m (https://www.reichelt.de/elko-radial-1-0-f-63-v-rm-2-0-85-c-2000h-20--rad-1-63-p15096.html?trstct=pol_1&nbc=1)m (https://www.reichelt.de/elko-radial-1-0-f-63-v-rm-2-0-85-c-2000h-20--rad-1-63-p15096.html?trstct=pol_1&nbc=1) spacing (https://www.reichelt.de/elko-radial-1-0-f-63-v-rm-2-0-85-c-2000h-20--rad-1-63-p15096.html?trstct=pol_1&nbc=1) | Reichelt.de
C22 | 1 | 100nF | MMK 100n 100 (https://www.reichelt.de/folienkondensator-100nf-100v-100-c-mmk-100n-100-p206605.html?search=MMK100n) Film (https://www.reichelt.de/folienkondensator-100nf-100v-100-c-mmk-100n-100-p206605.html?search=MMK100n) C (https://www.reichelt.de/folienkondensator-100nf-100v-100-c-mmk-100n-100-p206605.html?search=MMK100n)apacitor (https://www.reichelt.de/folienkondensator-100nf-100v-100-c-mmk-100n-100-p206605.html?search=MMK100n), 5m (https://www.reichelt.de/folienkondensator-100nf-100v-100-c-mmk-100n-100-p206605.html?search=MMK100n)m (https://www.reichelt.de/folienkondensator-100nf-100v-100-c-mmk-100n-100-p206605.html?search=MMK100n) spacing (https://www.reichelt.de/folienkondensator-100nf-100v-100-c-mmk-100n-100-p206605.html?search=MMK100n) | Reichelt.de
C23,C25 | 2 | 10uF 6,3V | RAD 10/35 (https://www.reichelt.de/elko-radial-10-f-35-v-rm-2-0-85-c-2000h-20--rad-10-35-p23716.html?trstct=pol_0&nbc=1) Electrolytic (https://www.reichelt.de/elko-radial-10-f-35-v-rm-2-0-85-c-2000h-20--rad-10-35-p23716.html?trstct=pol_0&nbc=1) C (https://www.reichelt.de/elko-radial-10-f-35-v-rm-2-0-85-c-2000h-20--rad-10-35-p23716.html?trstct=pol_0&nbc=1)apacitor (https://www.reichelt.de/elko-radial-10-f-35-v-rm-2-0-85-c-2000h-20--rad-10-35-p23716.html?trstct=pol_0&nbc=1), radial, (https://www.reichelt.de/elko-radial-10-f-35-v-rm-2-0-85-c-2000h-20--rad-10-35-p23716.html?trstct=pol_0&nbc=1) 2. (https://www.reichelt.de/elko-radial-10-f-35-v-rm-2-0-85-c-2000h-20--rad-10-35-p23716.html?trstct=pol_0&nbc=1)5m (https://www.reichelt.de/elko-radial-10-f-35-v-rm-2-0-85-c-2000h-20--rad-10-35-p23716.html?trstct=pol_0&nbc=1)m (https://www.reichelt.de/elko-radial-10-f-35-v-rm-2-0-85-c-2000h-20--rad-10-35-p23716.html?trstct=pol_0&nbc=1) spacing (https://www.reichelt.de/elko-radial-10-f-35-v-rm-2-0-85-c-2000h-20--rad-10-35-p23716.html?trstct=pol_0&nbc=1) | Reichelt.de
D1-D7,D9-D10 | 9 | BAT46 | BAT 46 (https://www.reichelt.de/kleinsignal-schottky-diode-100-v-150-ma-do-35-bat-46-p4853.html?search=bat46) Schottk (https://www.reichelt.de/kleinsignal-schottky-diode-100-v-150-ma-do-35-bat-46-p4853.html?search=bat46)y (https://www.reichelt.de/kleinsignal-schottky-diode-100-v-150-ma-do-35-bat-46-p4853.html?search=bat46) Diode (https://www.reichelt.de/kleinsignal-schottky-diode-100-v-150-ma-do-35-bat-46-p4853.html?search=bat46) | Reichelt.de
D8 | 1 | 1N4004 | 1N4004 (https://www.reichelt.de/gleichrichterdiode-400-v-1-a-do-41-1n-4004-p1726.html?&trstct=pos_0&nbc=1) D (https://www.reichelt.de/gleichrichterdiode-400-v-1-a-do-41-1n-4004-p1726.html?&trstct=pos_0&nbc=1)iode (https://www.reichelt.de/gleichrichterdiode-400-v-1-a-do-41-1n-4004-p1726.html?&trstct=pos_0&nbc=1) | Reichelt.de
R1-R4 | 4 | 4.7 KOhm | 1W 4. (https://www.reichelt.de/widerstand-metalloxyd-4-7-kohm-0207-1-0-w-5--1w-4-7k-p1822.html?search=1W+4,7K)7K (https://www.reichelt.de/widerstand-metalloxyd-4-7-kohm-0207-1-0-w-5--1w-4-7k-p1822.html?search=1W+4,7K) M (https://www.reichelt.de/widerstand-metalloxyd-4-7-kohm-0207-1-0-w-5--1w-4-7k-p1822.html?search=1W+4,7K)e (https://www.reichelt.de/widerstand-metalloxyd-4-7-kohm-0207-1-0-w-5--1w-4-7k-p1822.html?search=1W+4,7K)tal (https://www.reichelt.de/widerstand-metalloxyd-4-7-kohm-0207-1-0-w-5--1w-4-7k-p1822.html?search=1W+4,7K) Film (https://www.reichelt.de/widerstand-metalloxyd-4-7-kohm-0207-1-0-w-5--1w-4-7k-p1822.html?search=1W+4,7K) Resistor (https://www.reichelt.de/widerstand-metalloxyd-4-7-kohm-0207-1-0-w-5--1w-4-7k-p1822.html?search=1W+4,7K) | Reichelt.de
R5-R7,R10, R14-R16, R18,R19 | 9 | 10 KOhm | 1W 10K (https://www.reichelt.de/widerstand-metalloxyd-10-kohm-0207-1-0-w-5--1w-10k-p1779.html?search=1W+10K) Metal (https://www.reichelt.de/widerstand-metalloxyd-10-kohm-0207-1-0-w-5--1w-10k-p1779.html?search=1W+10K) Film (https://www.reichelt.de/widerstand-metalloxyd-10-kohm-0207-1-0-w-5--1w-10k-p1779.html?search=1W+10K) Resistor (https://www.reichelt.de/widerstand-metalloxyd-10-kohm-0207-1-0-w-5--1w-10k-p1779.html?search=1W+10K) | Reichelt.de
R8 | 1 | 1.2 KOhm | 1W 1. (https://www.reichelt.de/widerstand-metalloxyd-1-2-kohm-0207-1-0-w-5--1w-1-2k-p1768.html?search=1W+1,2K)2K (https://www.reichelt.de/widerstand-metalloxyd-1-2-kohm-0207-1-0-w-5--1w-1-2k-p1768.html?search=1W+1,2K) Metal (https://www.reichelt.de/widerstand-metalloxyd-1-2-kohm-0207-1-0-w-5--1w-1-2k-p1768.html?search=1W+1,2K) Film (https://www.reichelt.de/widerstand-metalloxyd-1-2-kohm-0207-1-0-w-5--1w-1-2k-p1768.html?search=1W+1,2K) Resistor (https://www.reichelt.de/widerstand-metalloxyd-1-2-kohm-0207-1-0-w-5--1w-1-2k-p1768.html?search=1W+1,2K) | Reichelt.de
R9 | 1 | 10 Ohm | 1W 10 (https://www.reichelt.de/widerstand-metalloxyd-10-ohm-0207-1-0-w-5--1w-10-p1776.html?search=1W+10) Metal (https://www.reichelt.de/widerstand-metalloxyd-10-ohm-0207-1-0-w-5--1w-10-p1776.html?search=1W+10) Film (https://www.reichelt.de/widerstand-metalloxyd-10-ohm-0207-1-0-w-5--1w-10-p1776.html?search=1W+10) Resistor (https://www.reichelt.de/widerstand-metalloxyd-10-ohm-0207-1-0-w-5--1w-10-p1776.html?search=1W+10) | Reichelt.de
R12,R13 | 2 | 3.3 KOhm | 1W 3. (https://www.reichelt.de/widerstand-metalloxid-3-3-kohm-0207-1-0-w-5--1w-3-3k-p1808.html?search=1W+3,3K)3K (https://www.reichelt.de/widerstand-metalloxid-3-3-kohm-0207-1-0-w-5--1w-3-3k-p1808.html?search=1W+3,3K) Metal (https://www.reichelt.de/widerstand-metalloxid-3-3-kohm-0207-1-0-w-5--1w-3-3k-p1808.html?search=1W+3,3K) Film (https://www.reichelt.de/widerstand-metalloxid-3-3-kohm-0207-1-0-w-5--1w-3-3k-p1808.html?search=1W+3,3K) Resistor (https://www.reichelt.de/widerstand-metalloxid-3-3-kohm-0207-1-0-w-5--1w-3-3k-p1808.html?search=1W+3,3K) | Reichelt.de
R17 | 1 | 2.2 KOhm | 1W 2. (https://www.reichelt.de/widerstand-metalloxyd-2-2-kohm-0207-1-0-w-5--1w-2-2k-p1794.html?search=1W+2,2K)2K (https://www.reichelt.de/widerstand-metalloxyd-2-2-kohm-0207-1-0-w-5--1w-2-2k-p1794.html?search=1W+2,2K) Metal (https://www.reichelt.de/widerstand-metalloxyd-2-2-kohm-0207-1-0-w-5--1w-2-2k-p1794.html?search=1W+2,2K) Film (https://www.reichelt.de/widerstand-metalloxyd-2-2-kohm-0207-1-0-w-5--1w-2-2k-p1794.html?search=1W+2,2K) Resistor (https://www.reichelt.de/widerstand-metalloxyd-2-2-kohm-0207-1-0-w-5--1w-2-2k-p1794.html?search=1W+2,2K) | Reichelt.de
RV1 | 1 | 10 KOhm | ACP 14-S 10K trim. Potentiometer (https://www.reichelt.de/de/de/shop/produkt/einstellpotentiometer_stehend_10_kohm_14_mm-110298) | Reichelt.de
Q1 | 1 | TIP125 | TIP125 (https://www.reichelt.de/de/de/shop/produkt/darlington-transistor_pnp_60v_5a_2w_to-220ab-217344) Darlington Transistor, PNP (https://www.reichelt.de/de/de/shop/produkt/darlington-transistor_pnp_60v_5a_2w_to-220ab-217344) | Reichelt.de
U1,U2,U13 | 3 | 74LS244 | SN 74LS244N TEX (https://www.reichelt.de/buffer-3-state-4-75--5-25-v-dil-20-sn-74ls244n-tex-p216948.html?search=74LS244) Buffer (https://www.reichelt.de/buffer-3-state-4-75--5-25-v-dil-20-sn-74ls244n-tex-p216948.html?search=74LS244), 3-State, DIL-20 (https://www.reichelt.de/buffer-3-state-4-75--5-25-v-dil-20-sn-74ls244n-tex-p216948.html?search=74LS244) | Reichelt.de
U3 | 1 | 74LS245 | LS 245 Transceiver, (https://www.reichelt.de/transceiver-octal-4-75--5-25-v-dip-20-ls-245-p10667.html?&trstct=pos_0&nbc=1) Octal (https://www.reichelt.de/transceiver-octal-4-75--5-25-v-dip-20-ls-245-p10667.html?&trstct=pos_0&nbc=1), DIL-20 (https://www.reichelt.de/transceiver-octal-4-75--5-25-v-dip-20-ls-245-p10667.html?&trstct=pos_0&nbc=1) | Reichelt.de
U4,U5 | 2 | 65C22 | W65C22S6TPG-14 6522 (https://www.reichelt.de/65xx-68xx-vielseitiger-schnittstellenadapter-pdip-40-w65c22s6tpg-14-p323440.html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) VIA (https://www.reichelt.de/65xx-68xx-vielseitiger-schnittstellenadapter-pdip-40-w65c22s6tpg-14-p323440.html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) | Reichelt, eBay, Mouser…
U6 | 1 | 74LS137 | LS 137 Decoder/MPX, 3 (https://www.reichelt.de/decoder-mpx-3-to-8-4-75--5-25-v-dil-16-ls-137-p10611.html?trstct=pos_0&nbc=1) to (https://www.reichelt.de/decoder-mpx-3-to-8-4-75--5-25-v-dil-16-ls-137-p10611.html?trstct=pos_0&nbc=1) 8, DIL-16 (https://www.reichelt.de/decoder-mpx-3-to-8-4-75--5-25-v-dil-16-ls-137-p10611.html?trstct=pos_0&nbc=1) | Reichelt.de

U7 | 1 | 74LS139 | LS 139 Decoder/MPX, 2 (https://www.reichelt.de/decoder-mpx-2-to-4-4-75--5-25-v-dil-16-ls-139-p10613.html?search=ls+139) to (https://www.reichelt.de/decoder-mpx-2-to-4-4-75--5-25-v-dil-16-ls-139-p10613.html?search=ls+139) 4, DIL-16 (https://www.reichelt.de/decoder-mpx-2-to-4-4-75--5-25-v-dil-16-ls-139-p10613.html?search=ls+139) | Reichelt.de
U8 | 1 | 28C256 | 28C256-150 EEPROM, 256Kb (32 K x 8), PDIP-28 (https://www.reichelt.de/eeprom-256-kb-32-k-x-8-5-v-150ns-pdip-28-28c256-150-p1945.html?search=28C256) | Reichelt.de
U9 | 1 | 74LS02 | LS 02 NOR-Gate, 2-Input, DIL-14 (https://www.reichelt.de/nor-gate-2-input-4-75--5-25-v-dil-14-ls-02-p10586.html?search=ls+02) | Reichelt.de
U10,U11 | 2 | 74LS257 | LS 257 Multiplexer, 3-State, DIL-16 (https://www.reichelt.de/multiplexer-3-state-4-75--5-25-v-dil-16-ls-257-p10675.html?search=ls+257) | Reichelt.de
U12 | 1 | 74LS241 | LS 241 (https://www.reichelt.de/buffer-3-state-4-75--5-25-v-dil-20-ls-241-p10663.html?search=ls241) Buffer (https://www.reichelt.de/buffer-3-state-4-75--5-25-v-dil-20-ls-241-p10663.html?search=ls241), 3-State, DIL-20 (https://www.reichelt.de/buffer-3-state-4-75--5-25-v-dil-20-ls-241-p10663.html?search=ls241) | Reichelt.de
U14 | 1 | DS1307+ | DS 1307 (https://www.reichelt.de/serielle-echtzeituhr-56byte-uhr-kalender-dip-8-ds-1307-p58149.html?search=DS+1307) Serial Real Time (https://www.reichelt.de/serielle-echtzeituhr-56byte-uhr-kalender-dip-8-ds-1307-p58149.html?search=DS+1307) Clock (https://www.reichelt.de/serielle-echtzeituhr-56byte-uhr-kalender-dip-8-ds-1307-p58149.html?search=DS+1307), 56byte (https://www.reichelt.de/serielle-echtzeituhr-56byte-uhr-kalender-dip-8-ds-1307-p58149.html?search=DS+1307) Clock (https://www.reichelt.de/serielle-echtzeituhr-56byte-uhr-kalender-dip-8-ds-1307-p58149.html?search=DS+1307)/ (https://www.reichelt.de/serielle-echtzeituhr-56byte-uhr-kalender-dip-8-ds-1307-p58149.html?search=DS+1307)Calenda (https://www.reichelt.de/serielle-echtzeituhr-56byte-uhr-kalender-dip-8-ds-1307-p58149.html?search=DS+1307)r (https://www.reichelt.de/serielle-echtzeituhr-56byte-uhr-kalender-dip-8-ds-1307-p58149.html?search=DS+1307), DIP-8 (https://www.reichelt.de/serielle-echtzeituhr-56byte-uhr-kalender-dip-8-ds-1307-p58149.html?search=DS+1307)

Reichelt.de

U15 | 1 | SN76489 | Digital Complex Sound Generator | eBay
U16 | 1 | 74LS165 | LS (https://www.reichelt.de/shift-register-8-bit-4-75--5-25-v-dil-16-ls-165-p10632.html?search=LS165) 165 (https://www.reichelt.de/shift-register-8-bit-4-75--5-25-v-dil-16-ls-165-p10632.html?search=LS165) Shift (https://www.reichelt.de/shift-register-8-bit-4-75--5-25-v-dil-16-ls-165-p10632.html?search=LS165) Register, 8-Bit (https://www.reichelt.de/shift-register-8-bit-4-75--5-25-v-dil-16-ls-165-p10632.html?search=LS165), DIL-16 (https://www.reichelt.de/shift-register-8-bit-4-75--5-25-v-dil-16-ls-165-p10632.html?search=LS165) | Reichelt.de
U17 | 1 | LM386N | LM386 DIP (https://www.reichelt.de/audio-ic-1-kanal-dip-8-lm-386-dip-p10494.html?&trstct=pos_0&nbc=1) Audio (https://www.reichelt.de/audio-ic-1-kanal-dip-8-lm-386-dip-p10494.html?&trstct=pos_0&nbc=1)-IC, 1-Chane (https://www.reichelt.de/audio-ic-1-kanal-dip-8-lm-386-dip-p10494.html?&trstct=pos_0&nbc=1)l, DIP-8 (https://www.reichelt.de/audio-ic-1-kanal-dip-8-lm-386-dip-p10494.html?&trstct=pos_0&nbc=1) | Reichelt.de
U18 | 1 | MT3608 | DC-DC (https://www.az-delivery.de/products/mt3608-dc-dc-step-up-modul-1) Stepup (https://www.az-delivery.de/products/mt3608-dc-dc-step-up-modul-1) Convert (https://www.az-delivery.de/products/mt3608-dc-dc-step-up-modul-1)er (https://www.az-delivery.de/products/mt3608-dc-dc-step-up-modul-1) | AZ-Delivery
U19 | 1 | 74LVC245 | 74LVC245Transceiver/Level-Shifter (https://csd-electronics.de/ICs/Logik/74LVX/74LVC/Logikgatter-74LVC245-DIP::5410.html) | csd-electronics.de or eBay, AliExpress, ...
U20 | 1 | NCP1117-3.3 | LDO-Voltage Regulator 3.3V SMD (https://www.reichelt.de/de/de/shop/produkt/ldo-regler_fest_3_3_v_sot-223-3-219149?PROVID=2788&gad_source=1) | Reichelt.de
X1 | 1 | 4.00 MHz | OSZI 4. (https://www.reichelt.de/quarzoszillator-4-00-mhz-oszi-4-000000-p13706.html?search=OSZI+4,000000)000000 (https://www.reichelt.de/quarzoszillator-4-00-mhz-oszi-4-000000-p13706.html?search=OSZI+4,000000) Cristal (https://www.reichelt.de/quarzoszillator-4-00-mhz-oszi-4-000000-p13706.html?search=OSZI+4,000000) Osc (https://www.reichelt.de/quarzoszillator-4-00-mhz-oszi-4-000000-p13706.html?search=OSZI+4,000000)illator 4. (https://www.reichelt.de/quarzoszillator-4-00-mhz-oszi-4-000000-p13706.html?search=OSZI+4,000000)00 MHz (https://www.reichelt.de/quarzoszillator-4-00-mhz-oszi-4-000000-p13706.html?search=OSZI+4,000000)

Reichelt.de

Y1 | 1 | 32.768 KHz | IQD LFXTAL002997 (https://www.reichelt.de/standardquarz-grundton-32-768-khz-iqd-lfxtal002997-p245393.html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) Cristal (https://www.reichelt.de/standardquarz-grundton-32-768-khz-iqd-lfxtal002997-p245393.html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), 32. (https://www.reichelt.de/standardquarz-grundton-32-768-khz-iqd-lfxtal002997-p245393.html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)768 KHz (https://www.reichelt.de/standardquarz-grundton-32-768-khz-iqd-lfxtal002997-p245393.html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)

Reichelt.de

BT1 | 1 | KZH 20-1 | K (https://www.reichelt.de/knopfzellenhalter-fuer-20-mm-kzh-20-1-p44621.html?&trstct=pol_11&nbc=1)ZH 20-1 (https://www.reichelt.de/knopfzellenhalter-fuer-20-mm-kzh-20-1-p44621.html?&trstct=pol_11&nbc=1) Button (https://www.reichelt.de/knopfzellenhalter-fuer-20-mm-kzh-20-1-p44621.html?&trstct=pol_11&nbc=1) Cell (https://www.reichelt.de/knopfzellenhalter-fuer-20-mm-kzh-20-1-p44621.html?&trstct=pol_11&nbc=1) Holder (https://www.reichelt.de/knopfzellenhalter-fuer-20-mm-kzh-20-1-p44621.html?&trstct=pol_11&nbc=1) for 20m (https://www.reichelt.de/knopfzellenhalter-fuer-20-mm-kzh-20-1-p44621.html?&trstct=pol_11&nbc=1)m (https://www.reichelt.de/knopfzellenhalter-fuer-20-mm-kzh-20-1-p44621.html?&trstct=pol_11&nbc=1) diameter (https://www.reichelt.de/knopfzellenhalter-fuer-20-mm-kzh-20-1-p44621.html?&trstct=pol_11&nbc=1)

Reichelt.de

BATT1 | 1 | CR2032 | Button Cell CR2032
J1 | 1 | DIN41612 Male, 3 rows, 2x32 pin | HAN 03 164 6921 (https://www.reichelt.de/messerleiste-c-gewinkelt-64-pol-han-03-164-6921-p293711.html?trstct=pol_1&nbc=1) C (https://www.reichelt.de/messerleiste-c-gewinkelt-64-pol-han-03-164-6921-p293711.html?trstct=pol_1&nbc=1) Female Connector (https://www.reichelt.de/messerleiste-c-gewinkelt-64-pol-han-03-164-6921-p293711.html?trstct=pol_1&nbc=1), (https://www.reichelt.de/messerleiste-c-gewinkelt-64-pol-han-03-164-6921-p293711.html?trstct=pol_1&nbc=1) 64-pin (https://www.reichelt.de/messerleiste-c-gewinkelt-64-pol-han-03-164-6921-p293711.html?trstct=pol_1&nbc=1) (A-C) (https://www.reichelt.de/messerleiste-c-gewinkelt-64-pol-han-03-164-6921-p293711.html?trstct=pol_1&nbc=1), (https://www.reichelt.de/messerleiste-c-gewinkelt-64-pol-han-03-164-6921-p293711.html?trstct=pol_1&nbc=1) pitch 2,5mm, (https://www.reichelt.de/messerleiste-c-gewinkelt-64-pol-han-03-164-6921-p293711.html?trstct=pol_1&nbc=1) angled (https://www.reichelt.de/messerleiste-c-gewinkelt-64-pol-han-03-164-6921-p293711.html?trstct=pol_1&nbc=1)

Reichelt.de

J2 | 1 | ASCII-Keyboard Connector | GS 16P IC-Socket 16-pin, (https://www.reichelt.de/index.html?ACTION=446&LA=3&nbc=1&q=gs16p) precision socket (https://www.reichelt.de/index.html?ACTION=446&LA=3&nbc=1&q=gs16p), (https://www.reichelt.de/index.html?ACTION=446&LA=3&nbc=1&q=gs16p) gold (https://www.reichelt.de/index.html?ACTION=446&LA=3&nbc=1&q=gs16p) plated (https://www.reichelt.de/index.html?ACTION=446&LA=3&nbc=1&q=gs16p) Use J9 instead if Keyboard Rev. 2 connected

Reichelt.de

J3,J4 | 1 | Port A 2x7-pin, Port B 2x8-pin | SL 2x17W 2,54 2x17-pin (https://www.reichelt.de/2x17pol-stiftleiste-gewinkelt-rm-2-54-sl-2x17w-2-54-p19493.html?trstct=pol_2&nbc=1) Pin Header, (https://www.reichelt.de/2x17pol-stiftleiste-gewinkelt-rm-2-54-sl-2x17w-2-54-p19493.html?trstct=pol_2&nbc=1) angled (https://www.reichelt.de/2x17pol-stiftleiste-gewinkelt-rm-2-54-sl-2x17w-2-54-p19493.html?trstct=pol_2&nbc=1), (https://www.reichelt.de/2x17pol-stiftleiste-gewinkelt-rm-2-54-sl-2x17w-2-54-p19493.html?trstct=pol_2&nbc=1) 2. (https://www.reichelt.de/2x17pol-stiftleiste-gewinkelt-rm-2-54-sl-2x17w-2-54-p19493.html?trstct=pol_2&nbc=1)5 (https://www.reichelt.de/2x17pol-stiftleiste-gewinkelt-rm-2-54-sl-2x17w-2-54-p19493.html?trstct=pol_2&nbc=1)4 mm (https://www.reichelt.de/2x17pol-stiftleiste-gewinkelt-rm-2-54-sl-2x17w-2-54-p19493.html?trstct=pol_2&nbc=1) spacing (https://www.reichelt.de/2x17pol-stiftleiste-gewinkelt-rm-2-54-sl-2x17w-2-54-p19493.html?trstct=pol_2&nbc=1)

Reichelt.de

J5 | 1 | DB25 Female | D (https://www.reichelt.de/d-sub-buchse-25-polig-gewinkelt-rm-7-2-d-sub-bu-25us-p6971.html?trstct=pol_13&nbc=1)-SUB BU 25US D (https://www.reichelt.de/d-sub-buchse-25-polig-gewinkelt-rm-7-2-d-sub-bu-25us-p6971.html?trstct=pol_13&nbc=1)-SUB- (https://www.reichelt.de/d-sub-buchse-25-polig-gewinkelt-rm-7-2-d-sub-bu-25us-p6971.html?trstct=pol_13&nbc=1)Connector Female (https://www.reichelt.de/d-sub-buchse-25-polig-gewinkelt-rm-7-2-d-sub-bu-25us-p6971.html?trstct=pol_13&nbc=1) 25-pin, (https://www.reichelt.de/d-sub-buchse-25-polig-gewinkelt-rm-7-2-d-sub-bu-25us-p6971.html?trstct=pol_13&nbc=1) angled (https://www.reichelt.de/d-sub-buchse-25-polig-gewinkelt-rm-7-2-d-sub-bu-25us-p6971.html?trstct=pol_13&nbc=1), (https://www.reichelt.de/d-sub-buchse-25-polig-gewinkelt-rm-7-2-d-sub-bu-25us-p6971.html?trstct=pol_13&nbc=1) depth 7,2mm (https://www.reichelt.de/d-sub-buchse-25-polig-gewinkelt-rm-7-2-d-sub-bu-25us-p6971.html?trstct=pol_13&nbc=1)

Reichelt.de

J6 | 1 | Box Header 2x10-pin | WSL 20G (https://www.reichelt.de/wannenstecker-20-polig-gerade-wsl-20g-p22825.html?&trstct=pos_0&nbc=1) Box Connector, 20-pin (https://www.reichelt.de/wannenstecker-20-polig-gerade-wsl-20g-p22825.html?&trstct=pos_0&nbc=1), straight (https://www.reichelt.de/wannenstecker-20-polig-gerade-wsl-20g-p22825.html?&trstct=pos_0&nbc=1) | Reichelt.de
J7 | 1 | Box Header 2x8-pin | WSL 16G (https://www.reichelt.de/wannenstecker-16-polig-gerade-wsl-16g-p22822.html?search=WSL16G) Box Connector, 16-pin (https://www.reichelt.de/wannenstecker-16-polig-gerade-wsl-16g-p22822.html?search=WSL16G), straight (https://www.reichelt.de/wannenstecker-16-polig-gerade-wsl-16g-p22822.html?search=WSL16G) | Reichelt.de
J9 | 1 | ASCII-Keyboard Connector, Box Header 2x8-pin | WSL 16G Box Connector, 16-pin, straight Use J2 instead if Keyboard Rev. 1 connected | Reichelt.de
J8, J10, J12, JP4 | 4 | Pin Header 1x4-pin, 1x2-pin, 1x2-pin, 1x2-pin | BKL 10120528 Pin Header, 20-pin, 2.54mm spacing, angled (https://www.reichelt.de/de/de/shop/produkt/stiftleiste_20-polig_gewinkelt_2_54mm-235665) | Reichelt.de

J14 | 1 | Pin Header 1x6-pin | BKL 10120204 (https://www.reichelt.de/stiftleiste-20-polig-raster-2-54mm-bkl-10120204-p235649.html?trstct=pol_7&nbc=1) Pin Header, 20-pin, 2. (https://www.reichelt.de/stiftleiste-20-polig-raster-2-54mm-bkl-10120204-p235649.html?trstct=pol_7&nbc=1)54m (https://www.reichelt.de/stiftleiste-20-polig-raster-2-54mm-bkl-10120204-p235649.html?trstct=pol_7&nbc=1)m (https://www.reichelt.de/stiftleiste-20-polig-raster-2-54mm-bkl-10120204-p235649.html?trstct=pol_7&nbc=1) spacing, straight (https://www.reichelt.de/stiftleiste-20-polig-raster-2-54mm-bkl-10120204-p235649.html?trstct=pol_7&nbc=1) | Reichelt.de
J15 | 1 | SD-Card Connector, Push-Push | ATOM SD01-AP20324 (https://www.pollin.de/p/sd-speicherkarten-sockel-atom-sd01-ap20324-451527) or WR-CRD SD Header 9 Pin | Pollin.de or de.rs-online.com
IC-Soc | 2 | IC-Socket 8-pin | GS 8P IC-Socket 8-pin, (https://www.reichelt.de/ic-sockel-8-polig-superflach-gedreht-vergold--gs-8p-p8231.html?search=gs8p) precision socket (https://www.reichelt.de/ic-sockel-8-polig-superflach-gedreht-vergold--gs-8p-p8231.html?search=gs8p), (https://www.reichelt.de/ic-sockel-8-polig-superflach-gedreht-vergold--gs-8p-p8231.html?search=gs8p) gold (https://www.reichelt.de/ic-sockel-8-polig-superflach-gedreht-vergold--gs-8p-p8231.html?search=gs8p) plated (https://www.reichelt.de/ic-sockel-8-polig-superflach-gedreht-vergold--gs-8p-p8231.html?search=gs8p) | Reichelt.de
IC-Soc | 1 | IC-Socket 14-pin | GS 14P IC-Socket 14-pin (https://www.reichelt.de/index.html?ACTION=446&LA=446&nbc=1&q=gs14p), (https://www.reichelt.de/index.html?ACTION=446&LA=446&nbc=1&q=gs14p) precision socket, (https://www.reichelt.de/index.html?ACTION=446&LA=446&nbc=1&q=gs14p) gold (https://www.reichelt.de/index.html?ACTION=446&LA=446&nbc=1&q=gs14p) plated (https://www.reichelt.de/index.html?ACTION=446&LA=446&nbc=1&q=gs14p) | Reichelt.de
IC-Soc | 6 | IC-Socket 16-pin | GS (https://www.reichelt.de/index.html?ACTION=446&LA=446&nbc=1&q=gs16p) 16P IC-Socket 16-pin (https://www.reichelt.de/index.html?ACTION=446&LA=446&nbc=1&q=gs16p), (https://www.reichelt.de/index.html?ACTION=446&LA=446&nbc=1&q=gs16p) precision socket, (https://www.reichelt.de/index.html?ACTION=446&LA=446&nbc=1&q=gs16p) gold (https://www.reichelt.de/index.html?ACTION=446&LA=446&nbc=1&q=gs16p) plated (https://www.reichelt.de/index.html?ACTION=446&LA=446&nbc=1&q=gs16p) | Reichelt.de
IC-Soc | 6 | IC-Socket 20-pin | GS 20P IC-Socket 20-pin (https://www.reichelt.de/index.html?ACTION=446&LA=3&nbc=1&q=gs20p), (https://www.reichelt.de/index.html?ACTION=446&LA=3&nbc=1&q=gs20p) precision socket (https://www.reichelt.de/index.html?ACTION=446&LA=3&nbc=1&q=gs20p), (https://www.reichelt.de/index.html?ACTION=446&LA=3&nbc=1&q=gs20p) gold (https://www.reichelt.de/index.html?ACTION=446&LA=3&nbc=1&q=gs20p) plated (https://www.reichelt.de/index.html?ACTION=446&LA=3&nbc=1&q=gs20p) | Reichelt.de
IC-Soc | 1 | IC-Socket 28-pin | GS 28P IC-Socket 28-pin (https://www.reichelt.de/ic-sockel-28-polig-superflach-gedreht-vergold--gs-28p-p8221.html?trstct=pos_0&nbc=1), (https://www.reichelt.de/ic-sockel-28-polig-superflach-gedreht-vergold--gs-28p-p8221.html?trstct=pos_0&nbc=1) precision socket, (https://www.reichelt.de/ic-sockel-28-polig-superflach-gedreht-vergold--gs-28p-p8221.html?trstct=pos_0&nbc=1) gold (https://www.reichelt.de/ic-sockel-28-polig-superflach-gedreht-vergold--gs-28p-p8221.html?trstct=pos_0&nbc=1) plated (https://www.reichelt.de/ic-sockel-28-polig-superflach-gedreht-vergold--gs-28p-p8221.html?trstct=pos_0&nbc=1)

Reichelt.de

IC-Soc | 2 | IC-Socket 40-pin | GS 40P IC-Socket 40-pin (https://www.reichelt.de/ic-sockel-40-polig-superflach-gedreht-vergold--gs-40p-p8225.html?search=GS40p), (https://www.reichelt.de/ic-sockel-40-polig-superflach-gedreht-vergold--gs-40p-p8225.html?search=GS40p) precision socket, (https://www.reichelt.de/ic-sockel-40-polig-superflach-gedreht-vergold--gs-40p-p8225.html?search=GS40p) gold (https://www.reichelt.de/ic-sockel-40-polig-superflach-gedreht-vergold--gs-40p-p8225.html?search=GS40p) plated (https://www.reichelt.de/ic-sockel-40-polig-superflach-gedreht-vergold--gs-40p-p8225.html?search=GS40p)

Reichelt.de

Dist | 4 | Spacers | VT DA4 18mm Spacers, Metal, M4, 18mm

Reichelt.de

# Backplane Parts

Slot 0 – Slot

3 | 4 | DIN 41612 Female, 3 rows, 2x32-pin | HAN 03 264 6825 (https://www.reichelt.de/federleiste-c-gerade-64-pol-han-03-264-6825-p293714.html?search=HAN+03+264+6825) C Male Connector (https://www.reichelt.de/federleiste-c-gerade-64-pol-han-03-264-6825-p293714.html?search=HAN+03+264+6825), (https://www.reichelt.de/federleiste-c-gerade-64-pol-han-03-264-6825-p293714.html?search=HAN+03+264+6825) straight (https://www.reichelt.de/federleiste-c-gerade-64-pol-han-03-264-6825-p293714.html?search=HAN+03+264+6825), 64-pin (https://www.reichelt.de/federleiste-c-gerade-64-pol-han-03-264-6825-p293714.html?search=HAN+03+264+6825) (A-C) (https://www.reichelt.de/federleiste-c-gerade-64-pol-han-03-264-6825-p293714.html?search=HAN+03+264+6825). (https://www.reichelt.de/federleiste-c-gerade-64-pol-han-03-264-6825-p293714.html?search=HAN+03+264+6825)

Reichelt.de

# Assembly Notes

Please note the installation direction of the crystal oscillator X1. Pin 1 of the oscillator is on the right, next to pin 7 of IC U9 (74LS02).

You may use soldering nails to solder the MT3608 voltage converter. I just took 1mm diameter pieces of silver wire. The output voltage of the converter must be set to 6.1V.

You should insulate the converter (with some plastic foil, cardboard, etc.) from the circuit board to prevent a short with the IO Board, because of a some protruding pins on the bottom side of the converter.

The total length of the cable between the parallel IO port of the Junior Computer ][ and the parallel port interconnect should be approx. 7.5 cm so that it can easily plugged in and out even with the strain reliefs of the ribbon cable connectors clipped in.

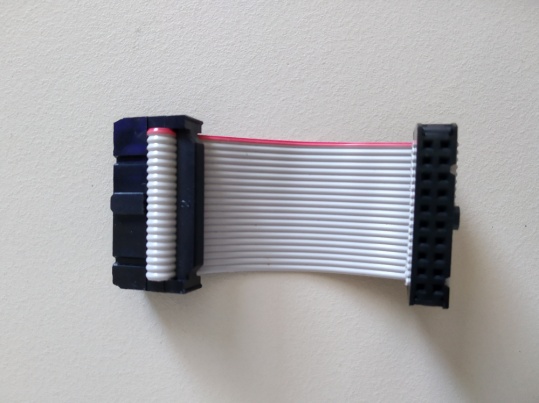
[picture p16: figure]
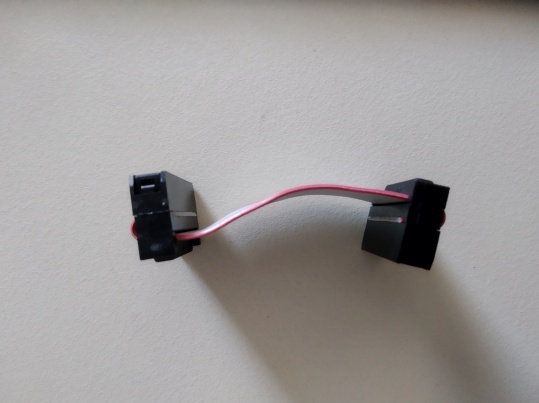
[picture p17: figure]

Place two solder joints on left and right side of the front of the SD card adapter to secure it against wobbling. There are small solder pads near the edge of the PCB for this purpose.

If necessary, fix the 32.768KHz crystal to the circuit board with solder or a drop of glue to prevent breaking the very thin connection wires. For this purpose, there is a small solder pad at the top of the crystal.

The pin headers J14 (Datasette) and J2 (SND OUT) are optional. The output of the SN76489 sound chip can be tapped at SND OUT if you want to use your own amplifier or some amplified PC speakers.

You can tap the signals of the I2C interface for your own on-board extensions at the two solder pads named SCL and SDA on the left side of the perf board. J8 can be used for external I2C extensions:

J8 (I2C) | GND (1) +5V (2) SDA (3) SCL (4).

Assignment of the two port connectors

J3 (Port A) | 14 GND | 13 GND
| 12 PA0 | 11 PA1
| 10 PA2 | 9 PA3
| 8 PA4 | 7 PA5
| 6 PA6 | 5 PA7
| 4 CA1 | 3 CA2
white mark | 2 +5V | 1 +5V |
J4 (Port B) | 16 GND | 15 GND
| 14 /RES | 13 /IRQ
| 12 PA0 | 11 PA1
| 10 PA2 | 9 PA3
| 8 PA4 | 7 PA5
| 6 PA6 | 5 PA7
| 4 CA1 | 3 CA2
white mark | 2 +5V | 1 +5V |

There are three solder jumpers K2, K3 and K4 located to the left of the expansion connector. One of them must be bridged to select the IO base address for the correct function of the IO Board.

Jumper | Base-Address
K2 | $0800
K3 | $0C00
K4 | $1000 (reserved for the Junior Computer ][ Floppy-/Graphics-Controller)

On the Junior Computer ][ CPU board, the DIP switches must be in position

$80 ON
$A0 OFF
$C0 OFF

Have fun

Jörg

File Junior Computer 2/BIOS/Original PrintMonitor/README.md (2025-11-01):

# Elektor Junior Computer Monitor

This is the original monitor program for the Elektor Junior Computer by Alois Nachtmann.

If you want to know how to use it, please visit Hans Ottens' website (http://retro.hansotten.nl/6502-sbc/elektuur-%20junior/), where you will find all the books and articles that have been published about the Elektor Junior Computer.

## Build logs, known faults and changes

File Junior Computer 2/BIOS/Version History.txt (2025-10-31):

Junior Computer ][ ROM Version History
======================================

Version 1.1.7
-------------

- Added TTY_OUT driver routine that handles right and up cursor ESC codes in the TTY driver.
  (code by Dietrich Lausberg)

Version 1.1.6
-------------

- Fixed an error in the interrupt service routine initializtation (INITVECT) for the initial BRKUSR 
  and IRQUSR routine hooks.

Version 1.1.5
-------------

- Skipped due to an inadvertently inserted bug (no comment).
  :(

Version 1.1.4
------------

- All new Card detection routines.
- Minor bug fixes.

Version 1.1.3
-------------

- Changed some ZP addresses to hopefully not colide with CPM-65 and EhBASIC...

Version 1.1.2
-------------

- Deleted 2x2ms Delay in SOUND_SENDBYTE routine.
- Support for 8 Bit ASCII Codes in PS2 Keyboard Driver routine.
- Fixed API entry points for SOUND routines.

Version 1.1.1
-------------

- Included Floppy-/Graphics-Card detection and initialization routine.
- Included Driver routine for Joystick Port.
- Included Driver routine for PS/2 Keyboard.
- Minor changes in Main IRQ routine for more compatibility with CPM-65.
- Added Monitor Return Vector in address $0000/$0001 used with command Q (for example return to M/OS-65 Operating System).
- Changes in SD_WR_BLK and SD_RD_BLK routines by Dietrich Lausenberg for faster SD-Card Read and Write.

Version 1.1.0
-------------

- Fixed a bug in SD_WR_BLK. The bug was found by German Classic Computing forum user Dietrich Lausberg. The response 
  byte was not read correctly after a write cycle, which also prevented the busy-waiting loop from executing correctly.
- Added new driver commands CMD_READ_BUF and CMD_WRITE_BUF.
- Fixed a bug in SYS_LD_BOOTBLK. The routine now uses the driver CMD routine instead of a SD_RD_LBLK_BUF call.
- Added support for MBR boot menus. 

Version 1.0.5
-------------

- Fixed a bug in LOAD_LBA. The lowest byte of the result address was not initialized if SD_TYPE was in BITMODE ($00).
- Boot Parameter Block is now moved to $400..$41F. Former start and length of boot partition at $05F8 is now no longer valid.
- SD_TYPE variable is moved from $EE to $1A to support CPM-65 from Dietrich Lausberg.

Version 1.0.4
-------------

- Fixed a bug in the XModem code. After setting the STDIN device from ASCII-Keyboard to TTY1, XModem crashed
  in the ReadByte routine.
- Fixed a bug in SYS_BOOT. Start and length of the boot partition is now saved to memory location $05F8 by the 
  boot routine.
- Fixed a bug in SYS_BOOT. BCS ($B0) op-code is no longer assumed to read from disk. Its now written to memory 
  location $0600 after the boot block is read. Because changing one of the first three bytes in the boot block 
  prevents windows from reading the disk (error -> disk not formated).

Version 1.0.3
-------------

- Fixed a bug in the disassembler code found by German Classic Computing forum user jet2bue.
  The opcodes $96 and $B6 were decoded to STX ADR,X and LDX ADR,X. 
  This is now corrected to STX ADR,Y and LDX ADR,Y. 
- Added SPI support
- Added SD-Card support
- Added boot device driver for SD-Card, Floppy and Harddisk drives
- Drivers can now be dynamically added to the driver list 

Version 1.0.2
-------------

- Support for Junior Computer ][ ASCII-Keyboard
- Fixed some errors in tape read/write routines caused by driver support changes (Version 1.0.1)
- Added patch to disable automatic baud rate detection (see hardware patch info)

Version 1.0.1
-------------

- Packed and somewhere optimized code.
- Includes a new and more flexible hardware driver support.
- Reordered basic system calls, so no moving of old code is necessary any longer ;)
- A list of basic BIOS system routines is now available.
- Changed Magic Number for language card detection. You need EhBasic 2.23 to run with this BIOS Version. 

Version 1.0
-----------

- Support for reading and writing to tape.

Version 0.9
-----------

- Autodetect for Junior Computer ][ IO/Language Card.
- Autodetect for installed programming language on IO/Language Card.
- I2C driver for IO/Language Card.
- Real Time Clock driver for IO/Language Card (not optimized - will be changed in previous versions)
- Included 'Set Date and Time' at home screen if RTC not initialized.
- Included printing of actual date and time at home screen.
- Included text Inverse, Flash and Normal mode.
- Optimized SETSTDIN and SETSTDOUT functions.
- Included more standard IO function calls.
- Fixed EhBasic warm start problem by moving some zero page variables to other locations.
- Fixed 7-segment display problem whith installed IO/Language Card after switching into the original monitor program. 

Version 0.8
-----------

- Included parallel port driver for printing on a standard parallel port printer (Epson FX80, Commodore MPS1230, ...).
- Added SETSTDOUT and SETSTDIN routines, to switch COUT, BOUT, CIN and CGET functions to different 
  input/output devices. Available Devices are: STDTTY (0) = Terminal and STDPPORT (1) = Printer.
- Added command P (print) to output a disassembler listing and PD (print dump) to output a hex dump to
  a connected parallel port printer.
- Disassembler listings are now no longer just one screen page long. Now, you can choose the start and end address
  of a disassemble listing. A listing can be interrupted by pressing the ESC key. 

Version 0.7
-----------

- ROM code start moved from F800 to E000.
- All new hex monitor command parser. Removed old extra command parser which was used for data exchange commands.
- Commands LM, SM for load/save via modem.
- Commands LP, SP for load/save via parallel port and LT, ST for load/save via tape are included, 
  but without any function (coming soon).
- Size reduced all new Disassembler.
- Processor status is shown if BRK opcode is executed or ST (NMI) key is pressed.
- Start address of data loaded via XModem is remembered, so a immediately following single G(o) command 
  can directly execute a loaded program code.

Version 0.6
-----------

- New command M(onitor) jumps to the original Junior Computer Monitor.
- Now includes a Disassembler which can be called by command L(ist).

Version 0.5
-----------

- Removed Interrupt driven receive, because of hanging of the Monitor if any key is pressed while
  a hex listing is send to the terminal. All character input routines are now polled versions.
- Simplified baud rate detection.
- Hex listing can now be interrupted by ESC key.
- Routines executed by the Monitor G(o) command can now return to the Monitor prompt by executing an RTS opcode.
- Saved of over 200 bytes by general source code optimization. 
- XMODEM buffer moved to $1500, which lies in the ACIA I/O and memory space.

Version 0.4
-----------

- Port of Daryl Rictor's 6502 XMODEM/CRC protocol implementation.
- Extended Monitor parser to support the XMODEM capabilities. 
- System Beep routine.
- Actual version is shown on welcome screen.
- Junior is beeping after powering up and hardware reset.

Version 0.3
-----------

- Simple timer controlled Delay routine.
- Auto baudrate detection of connected terminal. If no terminal connected, original Junior is executed.
- Fixed some ASCII view display issues.

Version 0.2
-----------

- Extended hex monitor view with two rows by eight bytes hex and one row ASCII view.
- Auto start for Print Monitor after power on and reset 

Version 0.1
-----------

- Port of Stephan Wozniaks Apple 1 Hex Monitor.
- Interrupt driven serial receive with 6551 ACIA.
- Serial transmition with fixed 9600 bauds, 8 bits, no parity, one stopbit.
- Character read/write routines.
- Welcome screen with simple menu.

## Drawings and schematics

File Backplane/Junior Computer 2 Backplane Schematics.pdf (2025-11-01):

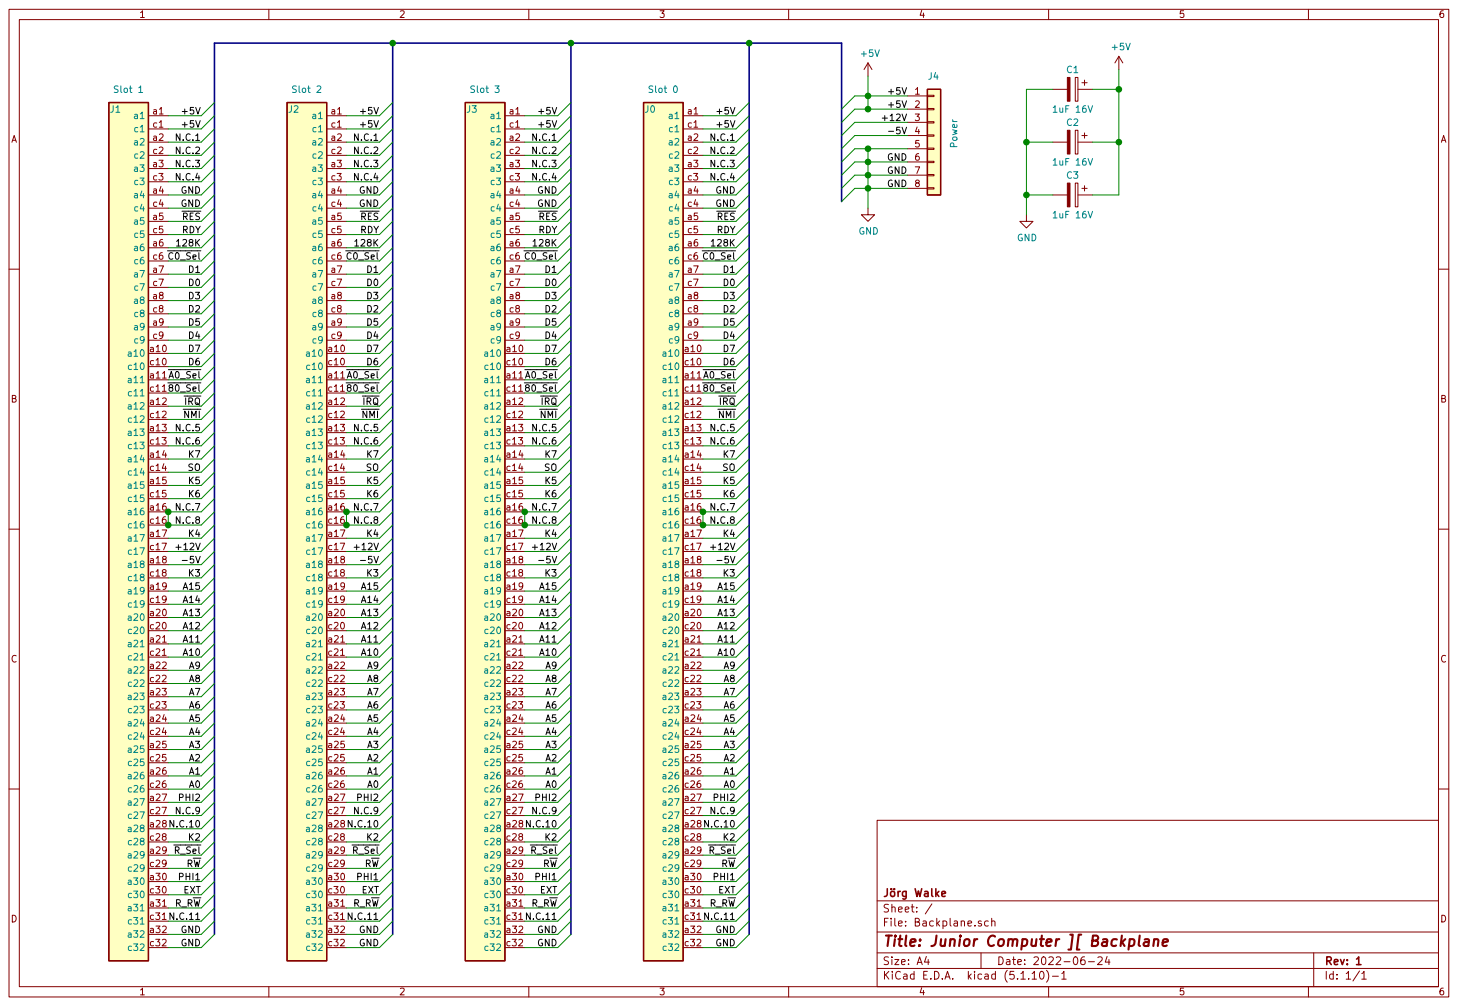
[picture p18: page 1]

File: Backplane.sch Sheet: / Jörg Walke

Id: 1/1 Title: Junior Computer ][ Backplane

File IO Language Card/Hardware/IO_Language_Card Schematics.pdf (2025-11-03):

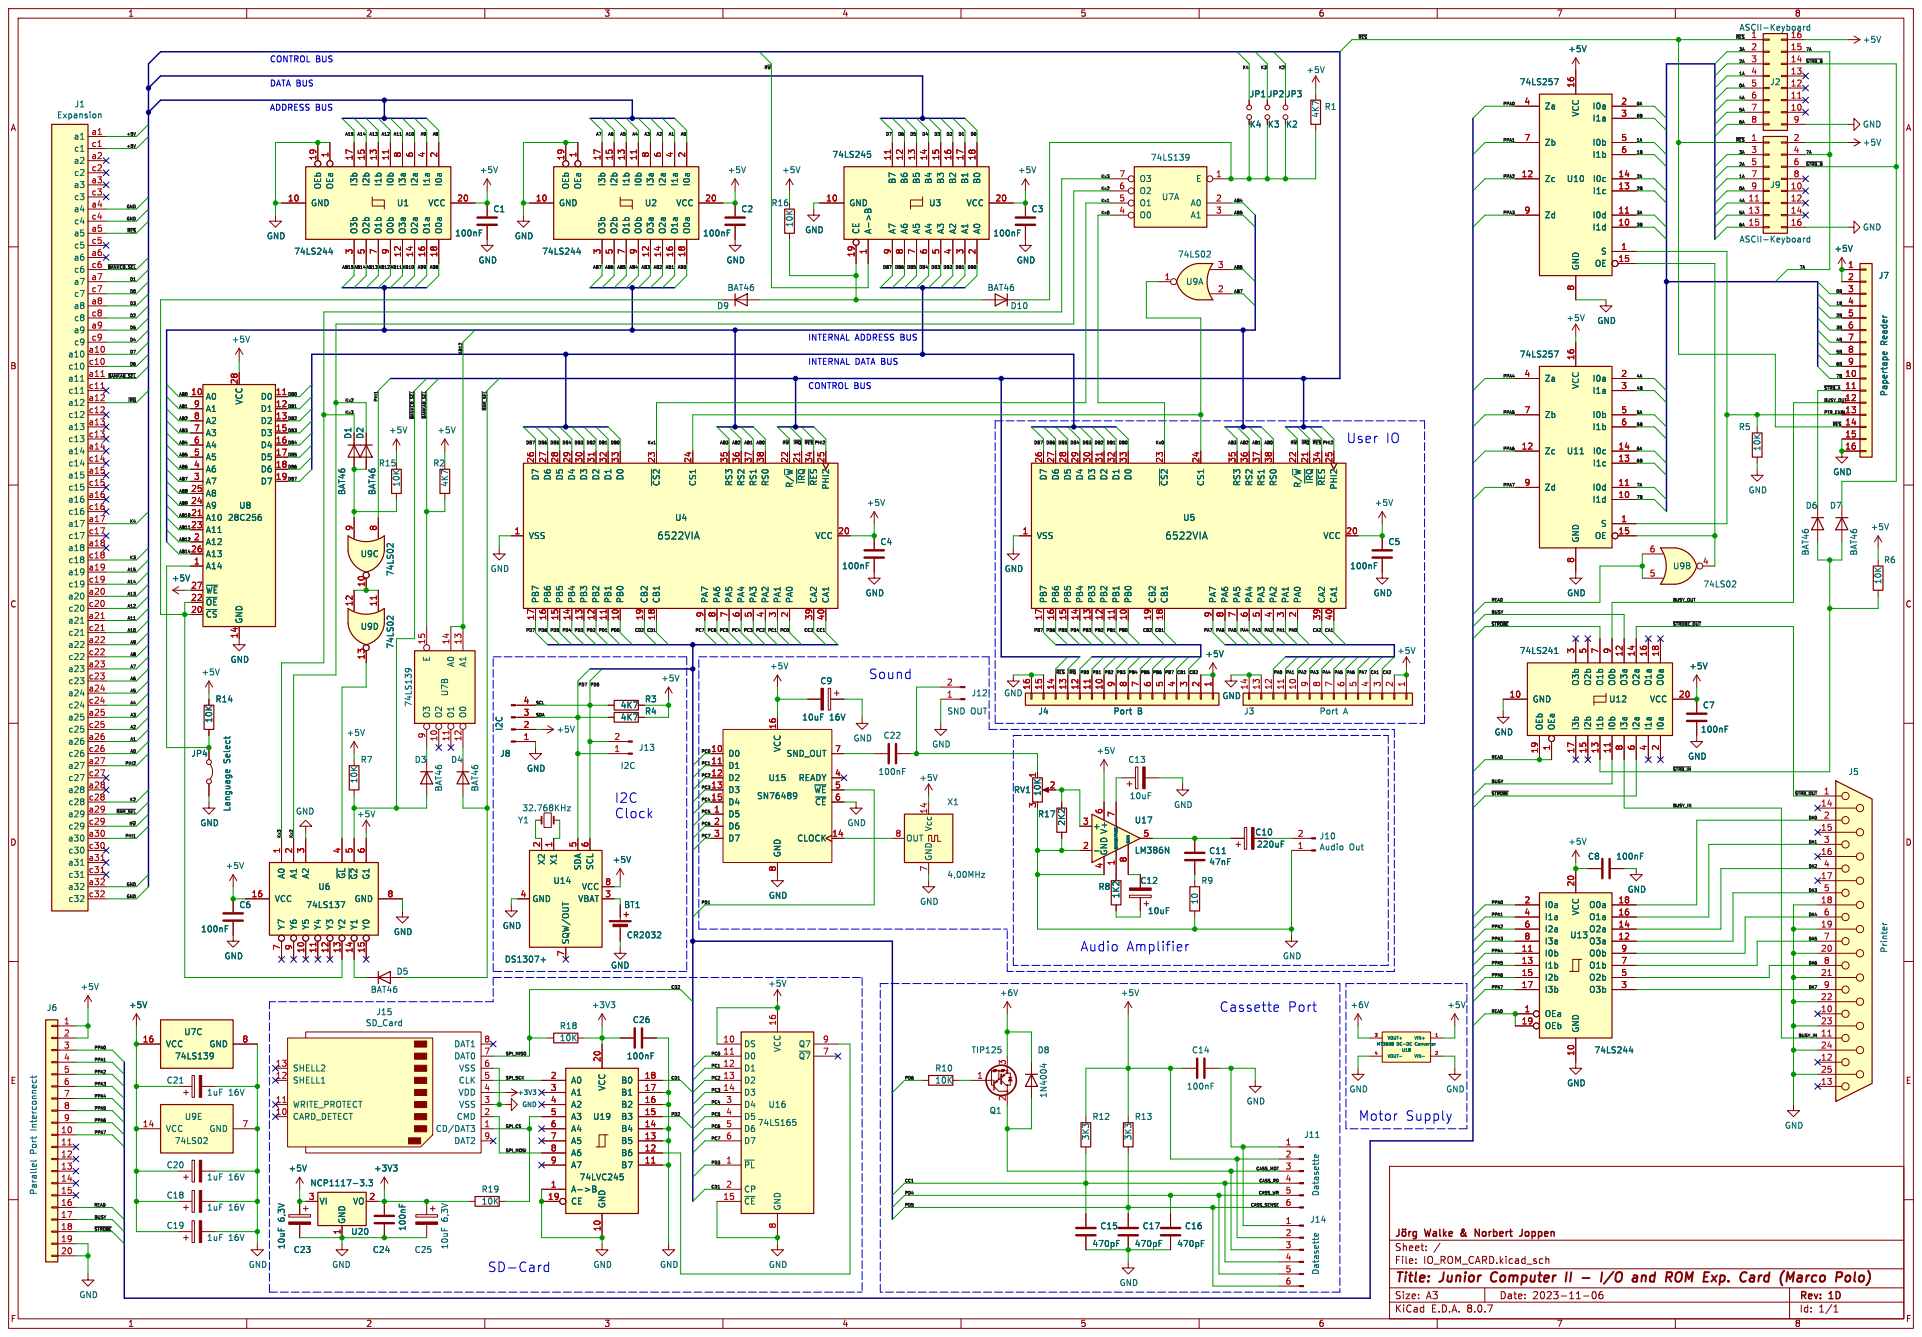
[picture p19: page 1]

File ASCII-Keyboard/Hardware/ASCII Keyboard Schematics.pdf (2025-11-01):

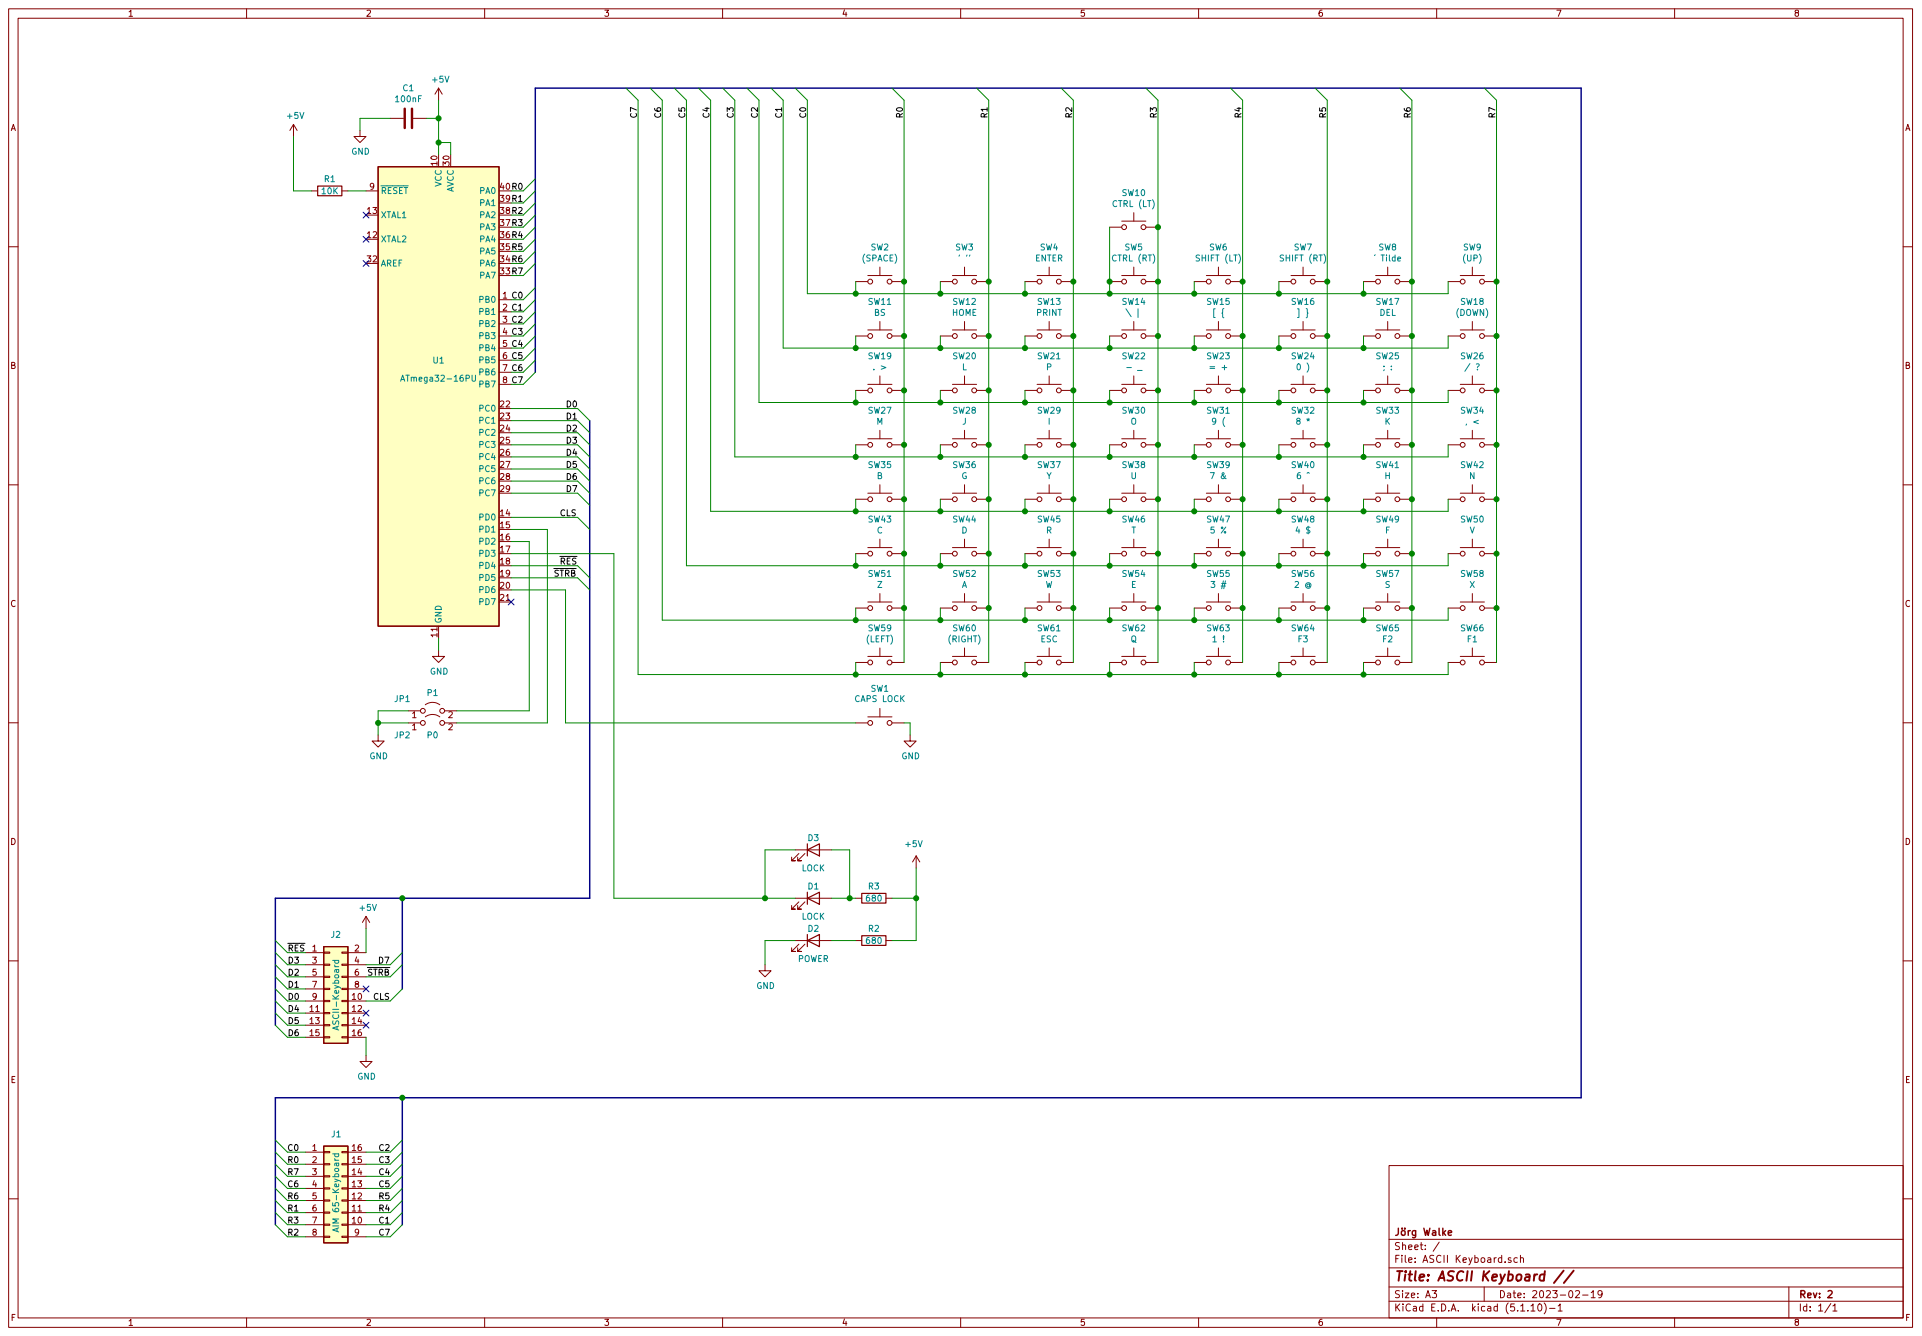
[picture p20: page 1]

File: ASCII Keyboard.sch Sheet: / Jörg Walke

Id: 1/1 Title: ASCII Keyboard //

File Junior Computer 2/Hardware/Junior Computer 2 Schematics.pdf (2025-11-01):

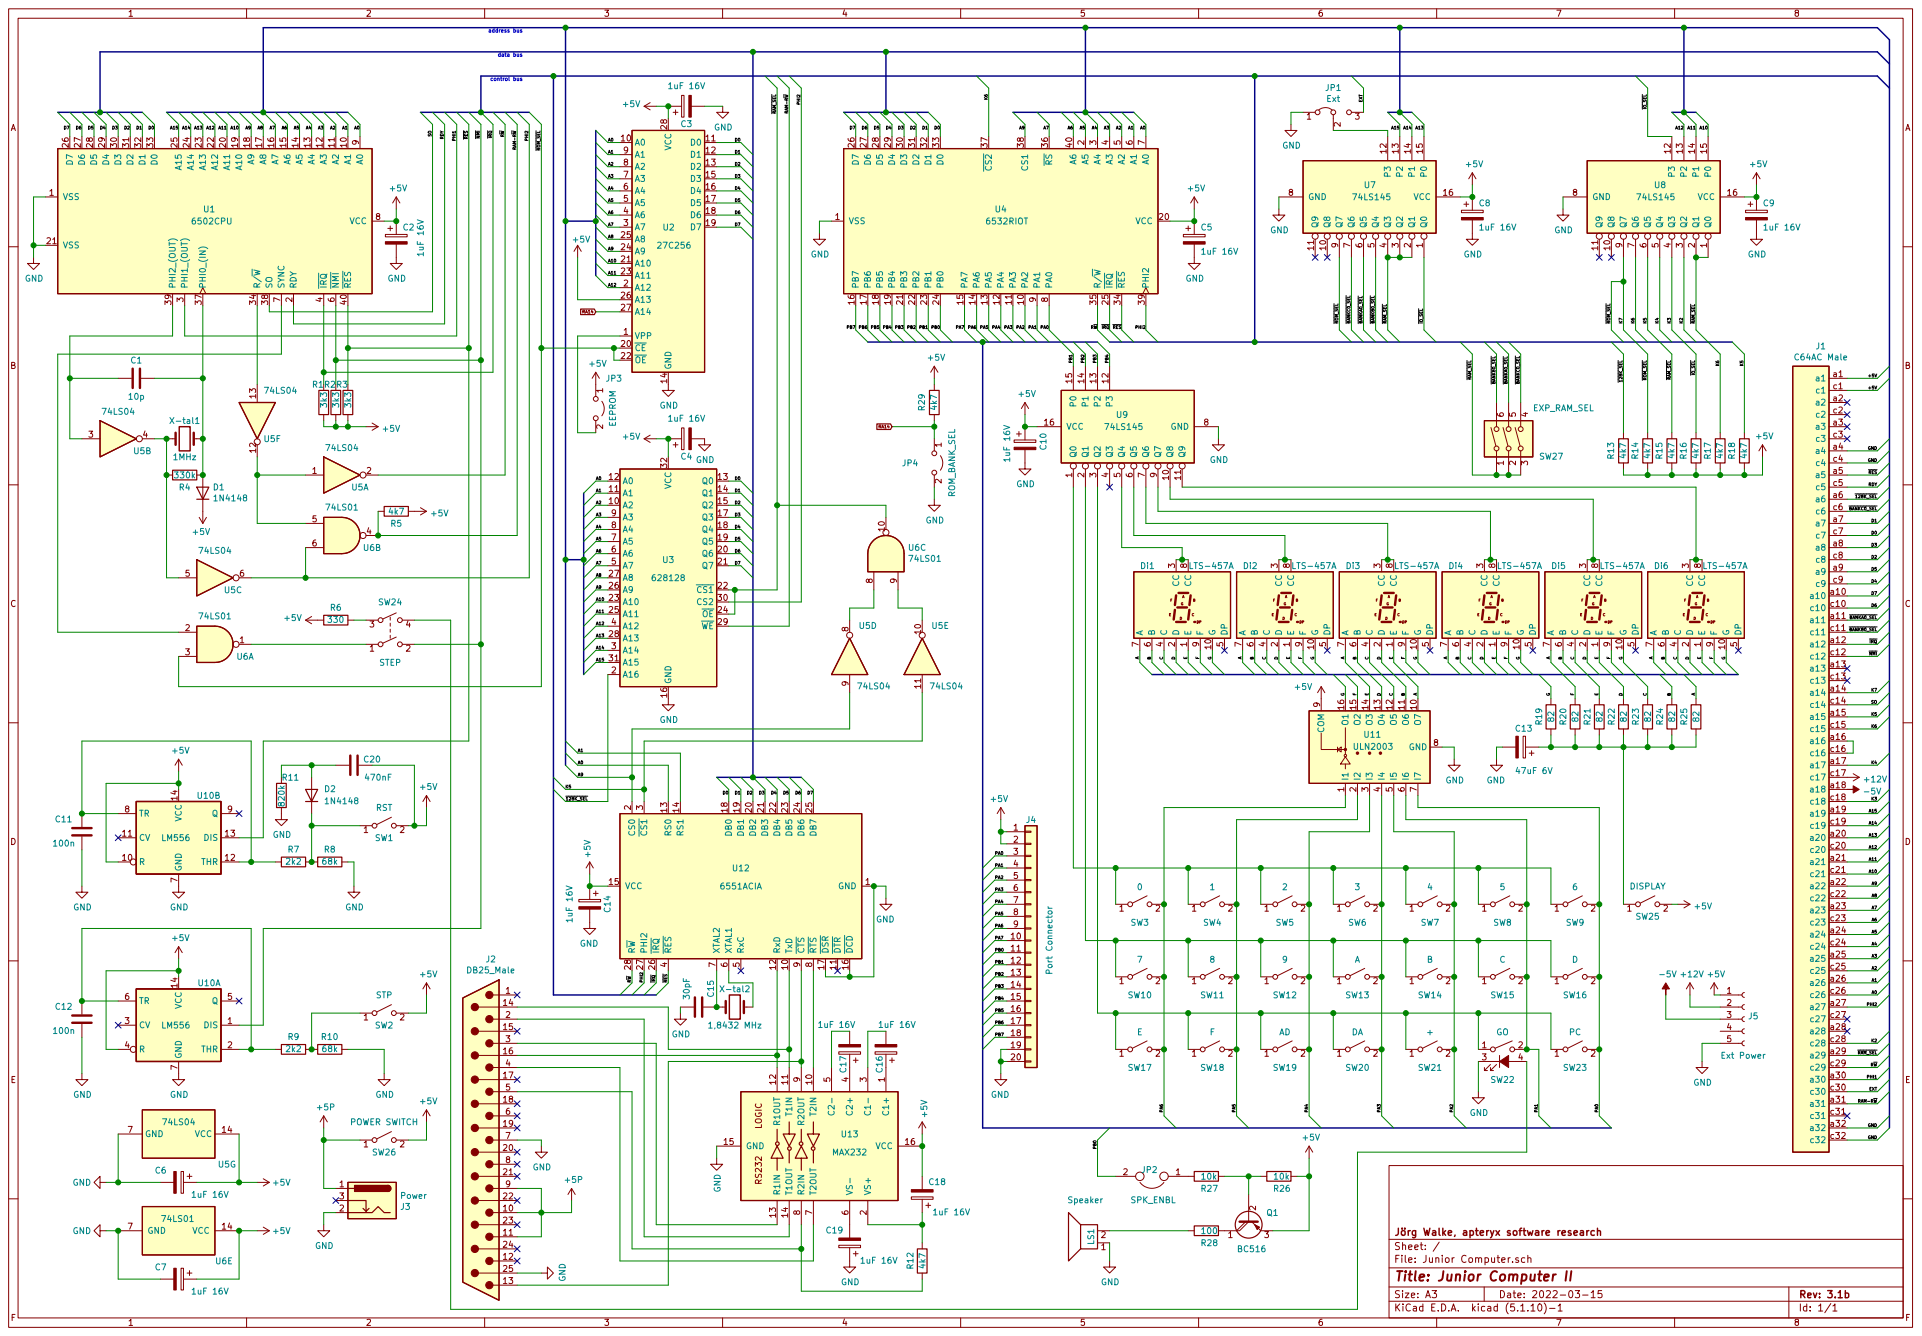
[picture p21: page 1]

2 A11 20 VSS 21 A12 22 A13 23 A14 24 A15 25 D7 26 D6 27 D5 28 D4 29 PHI1_(OUT) 3 D3 30 D2 31 D1 32 D0 33 R/W 34 PHI0_(IN) 37 SO 38 PHI2_(OUT) 39 IRQ

File: Junior Computer.sch Sheet: / Jörg Walke, apteryx software research

Id: 1/1 Title: Junior Computer II

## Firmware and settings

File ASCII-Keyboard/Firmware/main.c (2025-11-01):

/*
 * main.c
 *
 *  Junior Computer ][ Keyboard Firmware
 *
 *  Distributed under the Creative Commons Attribution 4.0 International License
 *  (see https://creativecommons.org/licenses/by/4.0/)
 *
 *  Created: 1/12/2023 5:09:44 PM
 *  Author: Jörg Walke
 *
 *  https://www.old-computer-tech.net
 */ 

#include <xc.h>

#define F_CPU  8000000L

#include <util/delay.h>

// Defined PortD pin constants

#define CLS       0x01 // ClearScreen output
#define P0        0x02 // P0 configuration input
#define P1        0x04 // P1 configuration input
#define LOCK_LED  0x08 // CapsLock Locked LED output
#define RESET     0x10 // Reset input/output
#define STROBE    0x20 // Key Strobe output
#define CAPS_LOCK 0x40 // CapsLock key input

// Some key codes

#define _RESET  255
#define _ALT    254
#define _SHIFTR 253
#define _SHIFTL 252
#define _CTRL   251
#define _NONE   250
#define _HOME   249

// Modifier key masks

#define CTRL_KEYS  0x08
#define SHIFT_KEYS 0x30

// Miscellaneous constants

#define DEBOUNCE_TIME 10    // debounce time in ms for caps lock key
#define SETTLE_TIME   20    // time in us between key checks

#define TYPEMATIC_RATE 25  // standard typematic rate in chars/s
#define REPEAT_DELAY   500 // standard delay before autorepeat in ms

// Global variables

uint8_t  capsLock      = 0; // caps lock status
uint8_t  capsLockUp    = 1; // caps lock key up mutex

uint8_t  keyStates[8];      // current key state list
uint8_t  lastStates[8];		// last key state list
uint16_t debounceCount = 0; // counter for key debounce timer
uint16_t delayCount    = 0; // counter for repeat delay timer
uint16_t repeatCount   = 0; // counter for repeat timer
uint8_t  modifierKeys;      // all modifier keys (CTRL SHIFT_L SHIFT_R)
uint8_t  lastModifiers;     // saved last modifiers
uint8_t  modifier;		    // modifier value (00 = Normal, 01 = Shift, 10 = Ctrl, 11 Shift+Ctrl)
uint8_t  currentKey;        // current pressed key
uint8_t  lang;              // keyboard language

uint8_t  autoRepeat    = 0; // signal that auto repeat is on

uint32_t repeatValue;       // initial repeat timer counter value
uint32_t delayValue;        // initial delay before-auto-repeat-timer counter value

char    *NormalChar;
uint8_t *ShiftChar;


// English US Keyboard Table

// Table of normal (unshifted) ASCII codes

  
                               // SPC    '   CR CTRL  SHL  SHR    ´   UP 
char NormalChar_US[64] =         { 32,  39,  13, 251, 252, 253,  96,  11,
	                           //  BS HOME PRNT    \    [    ]  DEL DOWN
									8, 249,  20,  92,  91,  93, 127,  10,
							   //   .    l    p    -    =    0    ;    /    		
								   46, 108, 112,  45,  61,  48,  59,  47,
							   //   m    j    i    o    9    8    k    ,	   
								  109, 106, 105, 111,  57,  56, 107,  44,
							   //   b    g    y    u    7    6    h    n	  
								   98, 103, 121, 117,  55,  54, 104, 110,
							   //   c    d    r    t    5    4    f    v	   
								   99, 100, 114, 116,  53,  52, 102, 118,
							   //   z    a    w    e    3    2    s    x	   
								  122,  97, 119, 101,  51,  50, 115, 120,
							   //LEFT RIGHT ESC    q    1   F3   F2   F1  
								    8,  21,  27, 113,  49,  19,  18,  17 };
									
// Table of shifted ASCII codes

                               // SPC    "   CR CTRL  SHL  SHR    ~   UP
uint8_t ShiftChar_US[64] =       { 32,  34,  13, 251, 252, 253, 126,  11,
		                       //  BS HOME PRNT    |    {    }  DEL DOWN
									8, 249,  20, 124, 123, 125, 127,  10,
							   //   >    L    P    _    +    )    :    ?
								   62,  76,  80,  95,  43,  41,  58,  63,
							   //   M    J    I    O    (    *    K    <
								   77,  74,  73,  79,  40,  42,  75,  60,
							   //   B    G    Y    U    &    ^    H    N
								   66,  71,  89,  85,  38,  94,  72,  78,
							   //   C    D    R    T    %    $    F    V
								   67,  68,  82,  84,  37,  36,  70,  86,
							   //   Z    A    W    E    #    @    S    X
								   90,  65,  87,  69,  35,  64,  83,  88,
							   //LEFT RIGHT ESC    Q    !   F3   F2   F1
								    8,  21,  27,  81,  33,  30,  29,  28 };
									

									
// German Keyboard Table

// Table of normal (unshifted) ASCII codes

                               // SPC    '   CR CTRL  SHL  SHR    ´   UP
char NormalChar_DE[64] =         { 32,  39,  13, 251, 252, 253,  96,  11,
	                           //  BS HOME PRNT    \    [    ]  DEL DOWN
	                                8, 249,  20,  92,  91,  93, 127,  10,
	                           //   .    l    p    -    =    0    ;    /
	                               46, 108, 112,  45,  61,  48,  59,  47,
	                           //   m    j    i    o    9    8    k    ,
	                              109, 106, 105, 111,  57,  56, 107,  44,
	                           //   b    g    z    u    7    6    h    n
	                               98, 103, 122, 117,  55,  54, 104, 110,
	                           //   c    d    r    t    5    4    f    v
	                               99, 100, 114, 116,  53,  52, 102, 118,
	                           //   y    a    w    e    3    2    s    x
	                              121,  97, 119, 101,  51,  50, 115, 120,
	                           //LEFT RIGHT ESC    q    1   F3   F2   F1
                                    8,  21,  27, 113,  49,  19,  18,  17 };

// Table of shifted ASCII codes

                               // SPC    "   CR CTRL  SHL  SHR    ~   UP
uint8_t ShiftChar_DE[64] =       { 32,  34,  13, 251, 252, 253, 126,  11,
	                           //  BS HOME PRNT    |    {    }  DEL DOWN
		                            8, 249,  20, 124, 123, 125, 127,  10,
	                           //   >    L    P    _    +    )    :    ?
	                               62,  76,  80,  95,  43,  41,  58,  63,
	                           //   M    J    I    O    (    *    K    <
	                               77,  74,  73,  79,  40,  42,  75,  60,
	                           //   B    G    Z    U    &    ^    H    N
	                               66,  71,  90,  85,  38,  94,  72,  78,
	                           //   C    D    R    T    %    $    F    V
	                               67,  68,  82,  84,  37,  36,  70,  86,
	                           //   Y    A    W    E    #    @    S    X
	                               89,  65,  87,  69,  35,  64,  83,  88,
	                           //LEFT RIGHT ESC    Q    !   F3   F2   F1
                                    8,  21,  27,  81,  33,  30,  29,  28 };

									
									
// *** Set typematic rate in chars/s
								
void SetTypematicRate(uint32_t typmaticRate) {
	
	repeatValue = 1000000/(8*SETTLE_TIME*typmaticRate)-48;
}

// Set auto repeat delay time in ms

void SetDelayTime(uint32_t delayTime) {
	
	delayValue = (delayTime*1000)/(8*SETTLE_TIME);
}

// *** Toggle CapsLock LED

void Toggle_LED() {
	
	if (capsLock) PORTD |= LOCK_LED;	// LED off
	else PORTD &= ~LOCK_LED;			// LED on
	capsLock = !capsLock;
}

// *** Reset keyboard to standard values;

void ResetKeyboard() {
	
	SetTypematicRate(TYPEMATIC_RATE);
	SetDelayTime(REPEAT_DELAY);
	currentKey = _NONE;
	for (uint8_t i = 0; i <= 7; i++) {
		keyStates[i]  = 0;
		lastStates[i] = 0;
	}
	// Read configuration jumpers
	
	if ((PIND & P0) == 0) lang  = 2;
	else lang = 0;
	if ((PIND & P1) == 0) lang |= 1;
	
	switch (lang)
	{
	case 0:
		NormalChar = NormalChar_US;
		ShiftChar  = ShiftChar_US;
		break;
	case 1:
	    NormalChar = NormalChar_DE;
	    ShiftChar  = ShiftChar_DE;
		break;
	case 2:
	  NormalChar = NormalChar_US;
	  ShiftChar  = ShiftChar_US;
	  break;
	case 3:
	  NormalChar = NormalChar_US;
	  ShiftChar  = ShiftChar_US;
	  break;
	}
	         
	
	PORTC  = 129;
}

// *** Check if incoming reset

void CheckReset() {
	
	if ((PIND & RESET) == 0) {
		_delay_ms(250);
		Toggle_LED();
		ResetKeyboard();
		_delay_ms(250);
		Toggle_LED();
		while ((PIND & RESET) == 0); // wait until reset line is HIGH
	}
}

// *** Initialize the keyboard

void InitKeyboard() {
	
	DDRA  = 0x00; // keyboard rows are all inputs
	PORTA = 0xFF; // enable all pull up resistors for row lines input
	DDRC  = 0xFF; // ASCII output port
	DDRD  = 0x29; // 6:CAPS_LOCK = I; 5:~STRB = O; 4:~RES = I/O; 3:LOCK_LED = O; 2:P1 = I; 1:P0 = I; 0:CLS = O
	PORTD = 0xFE;
	ResetKeyboard();
}

// *** Check if Caps Lock key is pressed

void CheckCapsLock() {
	
	if (capsLockUp) {
		if ((PIND & CAPS_LOCK) == 0) { // Caps Lock down
			_delay_ms(DEBOUNCE_TIME);
			Toggle_LED();
			capsLockUp = 0; // lock mutex
			autoRepeat = 0; // switch auto repeat off
		}
	}
	else {
		if (PIND & CAPS_LOCK) { // Caps Lock up
			_delay_ms(DEBOUNCE_TIME);
			capsLockUp = 1; // unlock mutex
		}
	}
}

// *** Set RESET line LOW for 250ms

void SignalReset() {
	
	DDRD  |= RESET;  // set pin 4 as output
	PORTD &= ~RESET; // set pin 4 LOW
	_delay_ms(250);
	PORTD |= RESET;  // set pin 4 HIGH
	DDRD &= ~RESET;  // set pin 4 as input
	delayCount = 0;
}

// *** Set CLS/HOME line HIGH for 25ms

void SignalCLS() {
	
	PORTD |= CLS;
	_delay_ms(25);
	PORTD &= ~CLS;
	delayCount = 0;
}

// *** Set Strobe LOW for 2us

void SignalStrobe() {
	
	PORTC = PORTC & 0x7F;  // reset bit7 to 0
	_delay_us(5);		   
	PORTC = PORTC | 0x80;  // set bit 7 to 1. Rising edge of bit7 is used by the Junior Computer ][ as data_avail flag
	_delay_us(2);          // data settle time
	PORTD &= ~STROBE;      // reset strobe to 0
	_delay_us(2);
	PORTD |= STROBE;	   // set strobe to 1	
}

// *** Send ASCII character to parallel port

void SendASCII(uint8_t code, uint8_t state) {
	
	if (state) {
		if (code == _RESET) SignalReset();
		else if (code < _NONE) {
			if (code == _HOME) {
				SignalCLS();
				code = 1;
			}
			PORTC = code | 0x80; // set ASCII code to output port and set MSB
			SignalStrobe();
		}
	}
	else PORTC = code | 0x80;    // set ASCII code to output port and set MSB
}

// *** Convert key matrix code into ASCII code

uint8_t GetASCII(uint8_t code) {
	
    uint8_t asciiCode = _NONE;
	if (code > 127) return asciiCode;
	switch (modifier) {
		case 0: asciiCode = NormalChar[code]; // get normal ASCII code
		    if (capsLock == 1 && asciiCode >= 97 && asciiCode <= 122) asciiCode -= 32; // if caps lock then make lower case letters upper case
			break;
		case 1: asciiCode = ShiftChar[code];  // get shifted ASCII code
		    if (capsLock == 1 && asciiCode >= 65 && asciiCode <= 90) asciiCode += 32; // if caps lock then make upper case letters lower case
			break;
		case 2:
		case 3: asciiCode = NormalChar[code]; // get normal ASCII code
		    if (asciiCode == 127 && modifier == 3) asciiCode = _RESET;     // Ctrl+Shift+Del pressed -> send RESET
			else if (asciiCode >= 96 && asciiCode <= 127) asciiCode -= 96; // generate control codes
			else if (asciiCode ==  8) asciiCode = 6;                       // left arrow becomes horizontal back tab
			else if (asciiCode == 10) asciiCode = 12;                      // down arrow becomes page down
			else if (asciiCode == 11) asciiCode = 24;                      // up arrow becomes page up
			else if (asciiCode == 21) asciiCode = 9;                       // right arrow becomes horizontal tab
			else if (asciiCode < 127) asciiCode = _NONE;			       // ignore all other chars
			break;
	}
	return asciiCode;
}

// *** Send key code to configured output port

void SendKeyCode(uint8_t key, uint8_t state) {
	
	if (state) currentKey = key;
	else if (key == currentKey) currentKey = _NONE;
	uint8_t asciiCode = GetASCII(currentKey);
	SendASCII(asciiCode,state); // send ASCII code to parallel port
}

// *** Check if any modifier key (Ctrl/Shift) is pressed, else return key state for current column

uint8_t CheckKeys(uint8_t col) {
	
	uint8_t keys = keyStates[col];
	if (col == 0) {							   // all modifier keys are in column 0
		modifier = 0;
		if (keys & SHIFT_KEYS) modifier = 1;   // any shift key pressed?
		if (keys & CTRL_KEYS)  modifier |= 2;  // any control key pressed?
		lastModifiers = modifierKeys;          // save last modifier state
		modifierKeys  = (keys >> 3) & 7;	   // get single modifier key status
		keys          &= 0xC7;				   // remove modifier keys from result
		lastModifiers ^= modifierKeys;		   // check for differences
		if (lastModifiers) {                   // any modifier key changed?
			if (lastModifiers & 1) SendKeyCode(_CTRL,   modifierKeys & 1);
			if (lastModifiers & 2) SendKeyCode(_SHIFTL, modifierKeys & 2);
			if (lastModifiers & 4) SendKeyCode(_SHIFTR, modifierKeys & 4);
		}
	}
	return keys;
}

// *** Scan keyboard matrix

void ScanKeys() {

	uint8_t keyState, changedKeys;
	for (uint8_t col = 0; col <= 7; col++) { // move a 0 bit through all column lines
		DDRB  = 1 << col;    // set all other columns as input to prevent short
		PORTB = ~(1 << col); // set current column to low
		_delay_us(SETTLE_TIME);
		keyState = ~PINA;
		if (keyState != keyStates[col]) { // any key has changed
			keyStates[col] = keyState;    // store new key state
			debounceCount  = 63;          // reset debounce timer to a total of 8*SETTLE_TIME*63 microseconds
			delayCount     = delayValue;  // reset delay counter
			autoRepeat     = 0;           // switch auto repeat off
		}
	}
	if (debounceCount == 1) {                    // no more keys has changed and debounce timer is over. Read the pressed keys.
		for (uint8_t col = 0; col <= 7; col++) { // move through all column lines
			keyState    = CheckKeys(col);
			changedKeys = keyState ^ lastStates[col];
			if (changedKeys) {                           // is any key in column changed?
				lastStates[col] = keyState;
				for (uint8_t row = 0; row <= 7; row++) { // check all rows if any is changed
					if (changedKeys & (1 << row)) {      // key at row/col is changed
						keyState = keyState & (1 << row);
						uint8_t key = 8*col+row;
						SendKeyCode(key,keyState);
					}
				}
			}
		}
	}
	else if ((currentKey != _NONE) && (debounceCount == 0)) { // start delay counter before auto repeat
		if (delayCount == 1) { // start auto repeat function
			autoRepeat  = 1;
			repeatCount = repeatValue;
		} 
		if (delayCount) delayCount--;
	}
	if (debounceCount) debounceCount--;
}

// *** Main loop

int main(void) {
	
	InitKeyboard();
    while(1) { 
		CheckReset();
		CheckCapsLock();
		ScanKeys();
		if (autoRepeat) {
			if (repeatCount) repeatCount--;
			else {
				repeatCount = repeatValue;
				if (currentKey < _NONE) SignalStrobe();
			}
		}
    }
}

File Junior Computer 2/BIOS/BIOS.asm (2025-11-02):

;{ASSEMBLER=A65}

; ******************************************************************************
; Junior Computer ][ BIOS Version 1.1.7
; by Joerg Walke
;
; first implementation 28.12.2021
; updated 30.10.2025
; by Joerg Walke
;
; Assembled With A65
;
; 20.03.2023
; A bug in the disassembler code was fixed by the
; German Classic Computing forum user jet2bue. See version history
;
; 01.08.2023
; A bug in SD_WR_BLK was fixed. The bug was found by German Classic Computing
; forum user Dietrich Lausberg. See version history
;
; 29.04.2024
; SPI & IRQ optimization by Dietrich Lausberg
;
; 26.05.24
; Changes in Fast SPI by Dietrich Lausberg
;
; ******************************************************************************
; To Do: (maybe in this order)
;
;  Paper Tape Reader Driver
;  ...and many more...
; ******************************************************************************

VERMAIN   	EQU     '1'    		; BIOS main version
VERPSUB    	EQU     '1'    		; BIOS primary sub version
VERSSUB		EQU	'7'		; BIOS secondary sub version

RETURN_VECT     EQU     $0001           ; return vector to monitor caller
RESET     	EQU  	$1C1D       	; original junior monitor reset vector

; Buffers **********************************************************************

STRBUF	  	EQU   	$1400    	; input string buffer at $1400

RBUFF     	EQU   	$1500    	; xmodem receive buffer at $1500

; Card Base Addresses **********************************************************

IOBASE		EQU	$14		; pointer to IO card base
IOBASEL		EQU	$14		; always $00
IOBASEH		EQU	$15		; K2 = $08, K3 = $0C, K4 = $10

FGCBASE	        EQU	$16		; pointer to Floppy-/Graphics-Controller card base
FGCBASEL	EQU	$16		; always $00
FGCBASEH	EQU	$17		; (K2 = $08, K3 = $0C,) should always K4 = $10

CARD3BASE	EQU	$18		; reserved (controller base)
CARD3BASEL	EQU	$18		; always $00
CARD3BASEH	EQU	$19		; K2 = $08, K3 = $0C, K4 = $10

; ******************************************************************************

FDC_MOTOR       EQU     $C1             ; current motor status

; ******************************************************************************

TICKCNT         EQU     $DA             ; current tick counter

; SPI/SD-Card Reader Variables *************************************************

SD_TYPE		EQU	$DB		; SD Card Type

; ACIA And Terminal Variables **************************************************

PSTR      	EQU   	$EA      	; output string Pointer
PSTRL     	EQU   	$EA      	; lower address byte of output string pointer
PSTRH     	EQU   	$EB      	; upper address byte of output string pointer
WBUF      	EQU   	$EC      	; ACIA character output buffer

; ******************************************************************************

DEVID		EQU	$03		; temp device id

; Device Driver Variables ******************************************************

PDEV		EQU	$DE		; device descriptor pointer
PDEVL    	EQU   	$DE      	; device descriptor pointer lo byte
PDEVH    	EQU   	$DF      	; device descriptor pointer hi byte

; XModem Transfer Variables ****************************************************

CRCL      	EQU   	$DC      	; CRC lo byte
CRCH      	EQU   	$DD     	; CRC hi byte

RETRYL    	EQU   	$DE      	; retry counter lo byte
RETRYH    	EQU   	$DF      	; retry counter hi byte

BLKEND      	EQU     $E0		; block end flag
BFLAG     	EQU   	$E1      	; block flag
BLKNO     	EQU   	$E2      	; block number
ERRCNT    	EQU   	$E3      	; error counter 10 is the limit

; Disassembler Variables *******************************************************

OPCODE		EQU	$E0		; current opcode
LINECNT		EQU	$E1		; number of disassembled lines
ADRMODE		EQU	$E2		; addressing mode
IBYTES		EQU	$E3		; instruction byte count

; I2C Variables ****************************************************************

I2C_DATA	EQU	$E0		; current I2C data byte

; TTY Variables ****************************************************************

BAUDRATE  	EQU   	$E0    		; current baud rate

; Tape Reader/Writer Variables *************************************************

CHECKSUM	EQU	$DC		; file checksum
OUTBYTE		EQU	$DD		; data byte read/written from/to tape

EQUFLAG		EQU	$E1		; file name equal flag

KEY_SENSE	EQU	$E5		; datasette key sense flag
BITCNT		EQU	$ED		; current read bit count

; SD-Card Command Buffer *******************************************************

SD_CMD		EQU	$DE		; CMD Byte
SD_PB3      	EQU   	$DF   		; Parameter Byte 3
SD_PB2		EQU   	$E0   		; Parameter Byte 2
SD_PB1      	EQU   	$E1   		; Parameter Byte 1
SD_PB0		EQU	$E2   		; Parameter Byte 0
SD_CRC		EQU	$E3   		; CRC Byte

BLKBUF		EQU	$DC             ; pointer to block buffer
BLKBUFL		EQU	$DC             ; lower byte of block buffer pointer
BLKBUFH		EQU	$DD             ; upper byte of block buffer pointer

; Pointer to Logical Block Address *********************************************

PLBA		EQU	$E6		; LBA pointer
PLBAL		EQU	$E6		; LBA pointer low byte
PLBAH		EQU	$E7		; LBA pointer high byte

; VIA2 Variables ***************************************************************

VIA_STATUS 	EQU	$E4 		; current VIA2 PortB output status

; Hex Monitor Variables ********************************************************

ASCL	  	EQU   	$E6     	; ASCII list start address low
ASCH      	EQU   	$E7     	; ASCII list start address high

STOL      	EQU   	$E8     	; store address Low
STOH      	EQU   	$E9     	; store address High

NUML      	EQU   	$F8     	; low number byte
NUMH	  	EQU   	$F9	 	; high number byte
ADRL      	EQU   	$FA     	; last address Low
ADRH      	EQU   	$FB     	; last address High
TEMP      	EQU   	$FC     	; temp storage
YSAV      	EQU   	$FD     	; Y register storage
PDBCNT    	EQU   	$FE     	; number of printed data bytes
MODE      	EQU   	$FF     	; current edit mode

PSAV            EQU     $EE

; Number String ****************************************************************

DIG0      	EQU   	$F8     	; 10^0 digit
DIG1	  	EQU   	$F9	 	; 10^1 digit
DIG2      	EQU   	$FA     	; 10^2 digit

; CPU Register Save ************************************************************

PCL		EQU	$EF		; program counter Low
PCH		EQU	$F0		; program counter High
PREG		EQU	$F1		; processor status register
SPUSER		EQU	$F2		; stack pointer
ACC		EQU	$F3		; accumulator
YREG		EQU	$F4		; y-register
XREG		EQU	$F5		; x-register

; Clock Variables **************************************************************

DIVCHAR		EQU	$F2             ; current divider char (. or / for date : for time)

; ACIA Registers ***************************************************************

DATA_REG  	EQU   	$1600    	; ACIA Data Register
STAT_REG  	EQU   	$1601    	; ACIA Status Register
COMM_REG  	EQU   	$1602    	; ACIA Command Register
CTRL_REG  	EQU   	$1603    	; ACIA Control Register

; RIOT RAM Area ****************************************************************

IO_INFO         EQU     $1A00           ; Initialization info call for IO card
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

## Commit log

2025-11-01 Add image of Junior Computer ][ board
    Added an image of the Junior Computer ][ board to the README.
2025-11-01 Update image path for Board Top in README
2025-11-01 Add README for Junior Computer II BIOS creation
    Document the process of creating and using the Junior Computer II BIOS, including details about the assembler, memory layout, and available BIOS images.
2025-11-01 Update README with memory and UART information
    Clarified memory access and UART communication details.
2025-11-01 Add instructions for 3D printed display cover
    Added information about 3D printed cover for display.
2025-11-01 Fix wording for 3D printed cover instruction
2025-11-01 Update README with assembly instructions and key strokes
    Added reference to Assembly Instruction.pdf for connector pinout and special key strokes.
2025-11-01 Update README for clarity on pin assignment
2025-11-01 Update image path for fuse bits in README
2025-11-01 Fix image path for fuse bits in README
2025-11-03 Add image reference for Junior Computer 2 case
    Added an image reference for the Junior Computer 2 case.
2025-11-03 Update README with wooden case description
    Added a description of the wooden case for JC2 and encouraged inspiration for building custom cases.
2025-11-03 Update README to remove case building details
    Removed outdated information about the wooden case and inspiration for building a case.
2025-11-03 Update README with finishing details for JC2 case
    Added a section about finishing the wooden case for JC2.
2025-12-15 Update README with W65C02S pin clarification
    Clarified the pin usage differences between W65C02S and 6502 CPUs in the README.
2025-12-15 Fix capitalization of 'Ground' in README
    Corrected capitalization of 'Ground' in instructions for W65C02S compatibility.
2025-12-15 Fix typos in README.md regarding pull-up resistors
